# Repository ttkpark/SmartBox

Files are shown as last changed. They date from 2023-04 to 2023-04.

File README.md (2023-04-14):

# SmartBox

프로젝트 기간 : 2020.02.13~2020.04.30

## 프로젝트 소개 및 개발 이유

- 주로 음식물 창고를 대상으로, 음식물 저장 창고 각 상자에 스마트 제품을 부착함으로써 음식물의 보관시기 등을 상자와 관리 PC를 통해 알 수 있도록 하여 효율적으로 음식물을 관리하는 시스템이다. 스마트 박스가 사물인터넷 망으로 연결되어 보관 이후 얼마나 시간이 지났는지 인터넷 또는 로컬 서버로 데이터를 수집하고 관리한다.

### 역할 소개
- 서버+설계 +웹 담당 : 서비스 회원가입, 박스들의 등록, 데이터 수집 DB관리
- 기기 개발 담당 : 창고의 스마트 박스 장치 개발, 남은 기한에 따른 e-paper 표시
- **응용 프로그램 개발 담당 : 창고에서 박스의 등록, 초기화, 관리를 담당하는 MFC 응용 프로그램을 개발,**

- 본인이 맡은 부분은
- `/3D Model`, `/SmartBoxDaemon`, `/SmartBoxWinMonitoring`, `/WZMS_Sensors Code`이다.

## 개발 요소

- 본인은 관리PC에서 동작하는 응용프로그램 개발을 담당하였다. MFC 기반으로 스마트 박스와 연결해야 했기에 PC와 그 박스들을 무선으로 연결할 수 있는 AP(Access Point)장치를 만들었다. 이 장치를 마스터키라고 한다. 즉, 응용프로그램과 마스터키 무선 장치를 제작하였다.

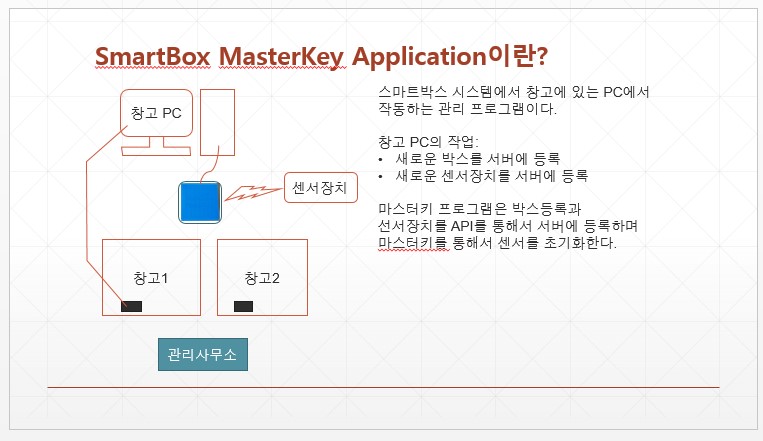
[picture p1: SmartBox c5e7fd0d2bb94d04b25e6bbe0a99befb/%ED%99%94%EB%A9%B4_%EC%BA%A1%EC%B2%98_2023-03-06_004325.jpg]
본인이 개발한 파트인 응용프로그램과 마스터키 무선 장치의 용도를 정의한 파워포인트 문서.


본인이 개발한 파트인 응용프로그램과 마스터키 무선 장치의 용도를 정의한 파워포인트 문서.

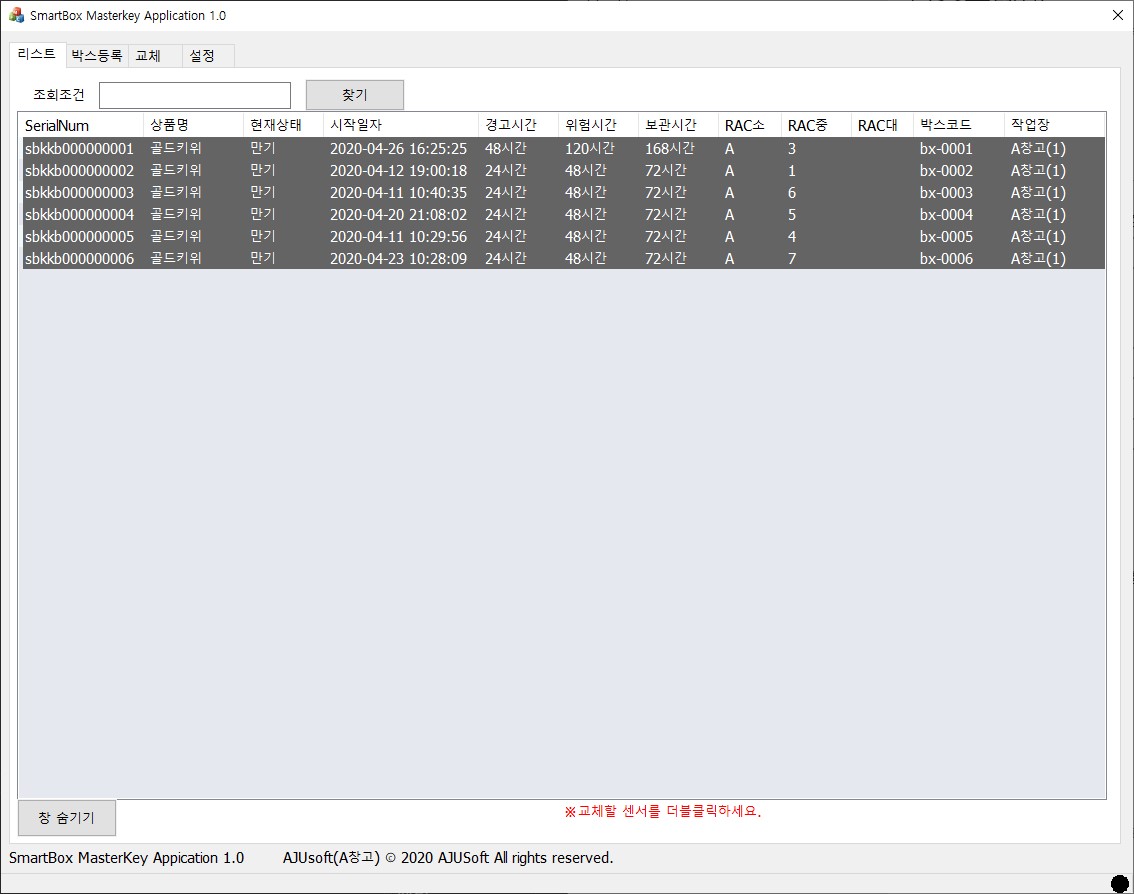
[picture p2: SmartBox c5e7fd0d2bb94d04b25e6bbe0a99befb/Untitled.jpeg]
응용프로그램의 동작화면. 모든 등록된 박스가 기한이 지난 상태이며 회색으로 표시돼 한눈에 확인할 수 있다.


응용프로그램의 동작화면. 모든 등록된 박스가 기한이 지난 상태이며 회색으로 표시돼 한눈에 확인할 수 있다.

- 스마트 박스 데이터를 업데이트 및 가져오기(서버와의 API 통신), 박스 등록하기(USB 시리얼로 마스터키와 통신), 언어설정(SQLite를 이용한 언어지원 관리), Tray Icon으로 숨기기 기능을 주로 구현했다.

## 어려움 및 극복사항

- MFC 교육을 받은 경험이 없어 모든 내용은 인터넷 검색과 대학교 교재를 찾아보아 구현하였다.
- 에러사항을 물어볼 곳이 없어 스스로 모든 문제를 인터넷을 통해 해결하였다.

## 협업 사항

- 응용프로그램 - 서버 간 API 통신으로 정보를 주고받았다. 이 때 서버 담당과의 의논을 통해 API 프로토콜을 결정했다.
- 박스 장치 - 응용프로그램 간 NRF 2.4Ghz RF 통신으로 정보를 주고받았다. 이 때의 프로토콜을 기기담당과 의논을 통해 결정했다.

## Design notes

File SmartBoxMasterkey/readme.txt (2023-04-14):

SmartBox Masterkey
마스터키 RF통신 , USB SerialComm 통신
기능
Lora 센서를 초기화, 컴퓨터 프로그램과 동기화하며 통신함.

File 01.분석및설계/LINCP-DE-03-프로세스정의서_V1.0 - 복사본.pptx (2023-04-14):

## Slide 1

목차
1. 사용자 정책 ........................................................................................................4
2. 업무처리 흐름도 ..........................................................................................6
(관리자 전체 흐름도).................................................................................5
PC-M-01 (로그인).............................................................................................7
PC-M-02 (로그아웃)...........................................................................................10
PC-M-03 (메인)...................................................................................12
PC-M-04 (회원정보변경).................................................................................15
PC-M-05 (헬프게시판)............................................................................18
PC-M-06 (관리자계정관리)....................................................................................22
PC-M-07 (DB관리)...................................................................................24
PC-M-08 (통계관리)......................................................................................33
PC-M-09 (게시판관리)…............................................................................38
PC-M-10 (예매데이터관제)…............................................................................48
PC-M-11 (회원관리).................................................................................................54
PC-M-12 (코드관리).................................................................................................63
PC-M-13 (시스템 연계 관리)...........................................................................................79
PC-M-14 (회원가입등록필드관리)..................................................................................................86

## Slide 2

0. 표기법

이벤트 시작/종료

데이터베이스

PC-01-01

프로세스

PC-01-01

수작업 프로세스

PC-01-06

문서

PC-01-06

수작업 문서

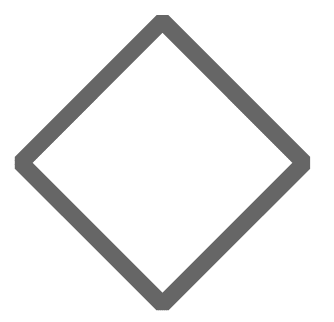
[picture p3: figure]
clip_image001

분기

데이터 흐름
(주요 엔터티 수준을 화살표 위에 표시)

※ 위 기호 외에 필요한 내용은 프로젝트 자체적으로 추가하여 사용할 수 있다.

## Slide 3

1. 사용자 정책

사용자 구분 | 사용자 분류 | 사용자 분류별 권한 | 예외사항 및 참고사항
관리자 | (일반)관리자 | *모든 기능 박스 등록 기능 센서 교체 기능 마스터키 포트 설정 기능 언어 설정 기능 선세 리스트 불러오기 기능 | 아이디/비밀번호 로그인 후 접근 가능

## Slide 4

관리자 전체 흐름도

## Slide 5

업무 처리 흐름도
단 계 | 설계 | 프로세스 ID | 없음 | 프로세스 명 | 관리자 전체 흐름도 | 작 성 자 | 박기호 | 승 인 자
설 명 | 공연예술통합관리시스템의 관리자 전체 업무 처리 흐름도

사용자구분 | 사용자분류 | 업무 절차
관리자 | 관리자, 슈퍼관리자

시작

로그인

센서 리스트

박스등록

센서교체

설정

다른 탭 클릭

종료버튼 클릭

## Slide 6

I. 로그인

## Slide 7

3. 업무처리 흐름도

PC-M-01

로그인

로그인

사용자구분 | 사용자분류 | 업무 절차
사용자 | 기획/제작사, 공연시설

N

시작

PC-M-01-01

로그인

PC-M-01-02

정보 일치 여부 확인

Y

인증 성공 여부

종료

N

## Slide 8

PC-M-01

로그인

로그인

엑티비티 | | | 수행자 | 산출물 | | 비고
ID | 명 | 설명 | | 입력 | 출력
PC-M-01-01 | 로그인 | 아이디/비밀번호를 통한 로그인 | 관리자 | 아이디/비밀번호
PC-M-01-02 | 정보 일치 여부 확인 | 아이디/비밀번호를 설정파일속에 설정된 서버로 전송 | 관리자 | 서버주소, 아이디/비밀번호 | 인증여부 | API(http)를 통해 송수신한다.

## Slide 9

II. 센서 리스트

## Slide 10

PC-M-02

메인

메인

사용자구분 | 사용자분류 | 업무 절차
관리자 | 관리자, 슈퍼관리자

PC-M-02-01

센서 리스트

시작

PC-M-02

센서 리스트

PC-M-02-02

검색

PC-M-02-03

창 숨기기(트레이)

PC-M-02-04

교체 센서 더블클릭

PC-M-04

교체 탭으로 이동

종료

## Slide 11

3. 업무처리 흐름도

PC-M-02

메인

메인

엑티비티 | | | 수행자 | 산출물 | | 비고
ID | 명 | 설명 | | 입력 | 출력
PC-M-02-01 | 센서 리스트 | 현재 작동 중인 센서들의 정보를 리스트로 표시 제일 윗부분을 클릭해 정렬을 할 수도 있음
PC-M-02-02 | 검색 | 텍스트박스에 있는 키워드를 리스트에 보이는 모든 내용에 검색하여 일치하는 행만 출력하도록 검색함
PC-M-02-03 | 창 숨기기(트레이) | 트레이 아이콘으로 창을 숨김
PC-M-02-04 | 교체 센서 더블클릭 | 더블클릭한 센서의 정보를 교체 탭으로 넘김. | | 더블클릭한 센서의 정보

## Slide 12

III. 박스 등록

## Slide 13

PC-M-03

메인

메인

사용자구분 | 사용자분류 | 업무 절차
관리자 | 관리자, 슈퍼관리자

시작

PC-M-03

박스등록

PC-M-03-02

센서/박스 준비 1

PC-M-03-03

센서/박스 준비 2

센서/박스 준비 1,2
*두가지 방법

PC-M-03-01

박스/센서 등록

종료

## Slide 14

3. 업무처리 흐름도

PC-M-03

메인

메인

엑티비티 | | | 수행자 | 산출물 | | 비고
ID | 명 | 설명 | | 입력 | 출력
PC-M-03-01 | 센서/박스 등록 | API를 통해서 서버에 박스/센서 정보 전송, 정상등록여부 확인 | | 입력한 정보, 박스 번호 | 성공여부
PC-M-03-02 | 선서/박스 준비1 | 센서를 먼저 켜는 경우(관리자 작업) | | | | 직접 수행
PC-M-03-03 | 선서/박스 준비2 | 박스번호를 먼저 찍는 경우(관리자 작업) | | | | 직접 수행

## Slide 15

PC-M-03-02

센서/박스 준비1

메인

사용자구분 | 사용자분류 | 업무 절차
관리자 | 관리자, 슈퍼관리자

시작

센서 전원ON

인식, 프로그램 메시지 띄움.

관리자 입력

※ 센서를
먼저 켜는
경우

전송버튼누름

센서 초기화, 박스 등록

종료

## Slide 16

PC-M-03-03

센서/박스 준비2

메인

사용자구분 | 사용자분류 | 업무 절차
관리자 | 관리자, 슈퍼관리자

시작

박스번호 입력

센서 인식 대기
사용자 입력 대기

※ 바코드를 먼저 찍는
경우

입력완성 및
전송버튼 누름

센서 초기화, 박스 등록

종료

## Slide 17

PC-M-03-01

센서/박스 등록

메인

사용자구분 | 사용자분류 | 업무 절차
관리자 | 관리자, 슈퍼관리자

시작

내용 확인

내용ok?

Y

센서 초기화

BOX등록
API전송

N

에러 메시지 표시.

종료

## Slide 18

IV. 센서 교체

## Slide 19

PC-M-04

메인

메인

사용자구분 | 사용자분류 | 업무 절차
관리자 | 관리자, 슈퍼관리자

시작

PC-M-04

메인

교체할 센서 더블클릭

새로운 센서 ON

교체 버튼 클릭

PC-M-04-01

종료

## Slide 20

3. 업무처리 흐름도

PC-M-04

메인

메인

엑티비티 | | | 수행자 | 산출물 | | 비고
ID | 명 | 설명 | | 입력 | 출력
PC-M-04-01 | 교체 버튼 클릭 | | | 센서 정보 | 성공여부

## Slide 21

V. 설정

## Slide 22

PC-M-05

메인

메인

사용자구분 | 사용자분류 | 업무 절차
관리자 | 관리자, 슈퍼관리자

PC-M-05-01

전송처별 예매DB수신현황

시작

PC-M-05

메인

PC-M-05-02

DB등록현황

PC-M-05-03

미매핑예매정보현황

PC-M-05-04

정보수정요청내역

종료

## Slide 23

3. 업무처리 흐름도

PC-M-05

메인

메인

엑티비티 | | | 수행자 | 산출물 | | 비고
ID | 명 | 설명 | | 입력 | 출력
PC-M-05-01 | 전송처별 예매 DB 수신현황 | 전일 기준 연계 시설 별 에매매수, 취소매수, 최종 매수 를 그래프 및 숫자로 표시
PC-M-05-02 | DB 등록현황 | 연계기관 및 OPENAPI를 통한 공연정보 등록 현황 을 표시 기획/제작사 등록 숫자 표시 공연시설 등록 숫자 표시
PC-M-05-03 | 미매핑정보현황 | 미매핑 숫자 표시
PC-M-05-04 | 정보수정요청내역 | 정보수정요청 건수 표시

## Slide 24

III. 메인

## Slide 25

PC-M-03

메인

메인

사용자구분 | 사용자분류 | 업무 절차
관리자 | 관리자, 슈퍼관리자

PC-M-03-01

마스터키 통신포트 설정

시작

PC-M-03

메인

PC-M-03-02

언어 설정

PC-M-03-03

센서 정보 불러오기

종료

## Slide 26

3. 업무처리 흐름도

PC-M-03

메인

메인

엑티비티 | | | 수행자 | 산출물 | | 비고
ID | 명 | 설명 | | 입력 | 출력
PC-M-03-01 | 마스터키 통신포트 설정 | 마스터키 연결 에 필요한 COM포트 설정 자동검색 기능 이용
PC-M-03-02 | 언어 설정 | 언어 설정
PC-M-03-03 | 센서 정보 불러오기 | 센서 리스트 다시 불러오기

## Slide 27

IX. 게시판 관리

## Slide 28

PC-M-09

게시판관리

게시판 관리

사용자구분 | 사용자분류 | 업무 절차
관리자 | 관리자/ 슈퍼관리자

시작

PC-M-09-01

공지사항 관리

PC-M-09

게시판 관리

PC-M-09-02

팝업존 관리

PC-M-09-03

FAQ 관리

PC-M-09-04

정보 수정 요청 관리

PC-M-09-05

OPEN API 신청 관리

PC-M-09-07

OPEN API FAQ 관리

PC-M-09-06

입력필드설명문구 관리

종료

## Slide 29

PC-M-09-01

공지사항 관리

공지사항 관리

사용자구분 | 사용자분류 | 업무 절차
관리자 | 관리자/ 슈퍼관리자

시작

PC-M-09-01-04

공지사항 삭제

PC-M-09-01-01

공지사항 목록

PC-M-09-01-05

공지사항 등록

PC-M-09-01-02-

공지사항 상세보기

PC-M-09-01-03

공지사항 수정

종료

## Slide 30

PC-M-09-01

공지사항 관리

공지사항 관리

엑티비티 | | | 수행자 | 산출물 | | 비고
ID | 명 | 설명 | | 입력 | 출력
PC-M-09-01-01 | 공지사항 목록 | 공지사항 목록 | 관리자/슈퍼관리자
PC-M-09-01-02 | 공지사항 상세 보기 | 공지사항 상세 보기 | 관리자/슈퍼관리자
PC-M-09-01-03 | 공지사항 수정 | 공지사항 수정 | 관리자/슈퍼관리자
PC-M-09-01-04 | 공지사항 삭제 | 공지사항 삭제 | 관리자/슈퍼관리자
PC-M-09-01-05 | 공지사항 등록 | 공지사항 등록 | 관리자/슈퍼관리자

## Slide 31

PC-M-09-02

팝업존 관리

팝업존 관리

사용자구분 | 사용자분류 | 업무 절차
관리자 | 관리자/ 슈퍼관리자

시작

PC-M-09-02-01

팝업존 목록

PC-M-09-02-04

팝업존 정보 삭제

PC-M-09-02-05

팝업존 등록

PC-M-09-02-02-

팝업존 상세 보기

종료

PC-M-09-02-03

팝업존 정보 수정

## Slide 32

PC-M-09-02

팝업존 관리

팝업 존 관리

엑티비티 | | | 수행자 | 산출물 | | 비고
ID | 명 | 설명 | | 입력 | 출력
PC-M-09-02-01 | 팝업존 목록 | 팝업존 목록 | 관리자/슈퍼관리자 | 팝업창명 | 팝업창명, 게시기간, 게시상태
PC-M-09-02-02 | 팝업존 상세 보기 | 팝업존 상세 보기 | 관리자/슈퍼관리자 | | 팝업창명, 게시기간, 그만보기 설정유무, 게시상태, 팝업내용
PC-M-09-02-03 | 팝업존 수정 | 팝업존 수정 | 관리자/슈퍼관리자 | | 팝업창명, 게시기간, 그만보기 설정유무, 게시상태, 팝업내용
PC-M-09-02-04 | 팝업존 삭제 | 팝업존 삭제 | 관리자/슈퍼관리자
PC-M-09-02-05 | 팝업존 등록 | 팝업존 등록 | 관리자/슈퍼관리자 | | 팝업창명, 게시기간, 그만보기 설정유무, 게시상태, 팝업내용

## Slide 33

PC-M-09-03

FAQ 관리

FAQ 관리

사용자구분 | 사용자분류 | 업무 절차
관리자 | 관리자/ 슈퍼관리자

시작

FAQ 질문
상세 보기

PC-M-09-03-02-

PC-M-09-03-03

FAQ 수정

PC-M-09-03-01

FAQ 목록

PC-M-09-03-04

FAQ 삭제

PC-M-09-03-05

FAQ 등록

종료

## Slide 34

PC-M-09-03

FAQ 관리

FAQ 관리

엑티비티 | | | 수행자 | 산출물 | | 비고
ID | 명 | 설명 | | 입력 | 출력
PC-M-09-03-01 | FAQ 목록 | FAQ 목록 | 관리자/슈퍼관리자 | 질문 제목 | 질문제목, 질문분류, 조회수, 등록일자
PC-M-09-03-02 | FAQ 상세 보기 | FAQ 상세 보기 | 관리자/슈퍼관리자 | | 질문제목, 질문분류, 답변내용, 조회수, 등록일자
PC-M-09-03-03 | FAQ 수정 | FAQ 수정 | 관리자/슈퍼관리자 | 질문제목, 질문분류, 답변내용
PC-M-09-03-04 | FAQ 삭제 | FAQ 삭제 | 관리자/슈퍼관리자
PC-M-09-04-05 | FAQ 등록 | FAQ 등록 | 관리자/슈퍼관리자 | 질문제목, 질문분류, 답변내용

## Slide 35

PC-M-09-04

정보수정요청관리

정보 수정 요청 관리

사용자구분 | 사용자분류 | 업무 절차
관리자 | 관리자/ 슈퍼관리자

시작

정보 수정 요청
상세 보기

PC-M-09-04-02-

PC-M-09-04-01

PC-M-09-04-03

정보 수정 요청
목록

정보 수정 요청
삭제

PC-M-09-04-04

정보 수정 요청 답변

종료

PC-M-09-04-05

정보 수정 요청 접수 처리

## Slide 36

PC-M-09-04

정보 수정 요청 관리

정보 수정 요청 관리

엑티비티 | | | 수행자 | 산출물 | | 비고
ID | 명 | 설명 | | 입력 | 출력
PC-M-09-04-01 | 정보 수정 요청 목록 | 정보 수정 요청 목록 | 관리자/슈퍼관리자 | 요청대상, 작성자 | 구분, 요청대상, 요청자, 진행상태, 최종수정일
PC-M-09-04-02 | 정보 수정 요청 상세 보기 | 정보 수정 요청 상세 보기 | 관리자/슈퍼관리자 | | 요청대상, 요청내용, 첨부파일, 요청자, 요청자 연락처, 요청자 이메일주소, 진행상태, 정보출처
PC-M-09-04-03 | 정보 수정 요청 삭제 | 정보 수정 요청 삭제 | 관리자/슈퍼관리자
PC-M-09-04-04 | 정보 수정 요청 답변 | 정보 수정 요청 답변 | 관리자/슈퍼관리자 | 진행상태 | | 답변은 이메일/SMS로 발송됨.
PC-M-09-04-05 | 정보 수정 요청 접수 처리 | 정보 수정 요청 접수 처리 | 관리자/슈퍼관리자

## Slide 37

PC-M-09-05

OPEN API 신청 관리

OPEN API 신청 관리

사용자구분 | 사용자분류 | 업무 절차
관리자 | 관리자/ 슈퍼관리자

시작

PC-M-09-05-02-

OPEN API 신청
상세 보기

PC-M-09-05-01

OPEN API 신청
목록

종료

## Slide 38

PC-M-09-05

OPEN API 신청 관리

OPEN API 신청 관리

엑티비티 | | | 수행자 | 산출물 | | 비고
ID | 명 | 설명 | | 입력 | 출력
PC-M-09-05-01 | OPEN API 신청 목록 | OPEN API 신청 목록 | 관리자/슈퍼관리자 | 신청자, 기관 | 신청자, 기관, 신청 분류
PC-M-09-05-02 | OPEN API 신청 상세 보기 | OPEN API 신청 상세 보기 | 관리자/슈퍼관리자 | | 신청자, 연락처, 이메일, 기관, 신청분류, 발급 KEY, 신청 일자

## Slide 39

PC-M-09-07

OPEN API FAQ 관리

OPEN API FAQ 관리

사용자구분 | 사용자분류 | 업무 절차
관리자 | 관리자/ 슈퍼관리자

시작

OPEN API FAQ 질문
상세 보기

PC-M-09-07-02-

PC-M-09-07-03

OPEN API FAQ 수정

PC-M-09-07-01

OPEN API FAQ 목록

PC-M-09-07-04

OPEN API FAQ 삭제

PC-M-09-07-05

OPEN API FAQ 등록

종료

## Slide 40

PC-M-09-07

OPEN API FAQ 관리

OPEN API FAQ 관리

엑티비티 | | | 수행자 | 산출물 | | 비고
ID | 명 | 설명 | | 입력 | 출력
PC-M-09-07-01 | OPEN API FAQ 목록 | OPEN API FAQ 목록 | 관리자/슈퍼관리자 | 질문 제목 | 질문제목, 질문분류, 조회수, 등록일자
PC-M-09-07-02 | OPEN API FAQ 상세 보기 | OPEN API FAQ 상세 보기 | 관리자/슈퍼관리자 | | 질문제목, 질문분류, 답변내용, 조회수, 등록일자
PC-M-09-07-03 | OPEN API FAQ 수정 | OPEN API FAQ 수정 | 관리자/슈퍼관리자 | 질문제목, 질문분류, 답변내용
PC-M-09-07-04 | OPEN API FAQ 삭제 | OPEN API FAQ 삭제 | 관리자/슈퍼관리자
PC-M-09-07-05 | OPEN API FAQ 등록 | OPEN API FAQ 등록 | 관리자/슈퍼관리자 | 질문제목, 질문분류, 답변내용

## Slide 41

PC-M-09-06

입력필드설명문구 관리

입력필드설명문구 관리

사용자구분 | 사용자분류 | 업무 절차
관리자 | 관리자/ 슈퍼관리자

시작

입력필드설명문구
상세 보기

PC-M-09-06-03-

PC-M-09-06-05

입력필드설명문구 수정

PC-M-09-06-01

입력필드설명문구 목록

PC-M-09-06-06

입력필드설명문구 삭제

PC-M-09-06-04

입력필드설명문구 등록

종료

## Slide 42

PC-M-09-06

입력필드설명문구 관리

입력필드설명문구 관리

엑티비티 | | | 수행자 | 산출물 | | 비고
ID | 명 | 설명 | | 입력 | 출력
PC-M-09-06-01 | 입력필드설명문구 목록 | 입력필드설명문구 목록 | 관리자/슈퍼관리자 | | 제목, 조회수, 등록일자
PC-M-09-06-02 | 입력필드설명문구 검색 | 입력필드설명문구 검색 기능 | 관리자/슈퍼관리자 | | 제목, 조회수, 등록일자
PC-M-09-06-03 | 입력필드설명문구 등록 | 입력필드설명문구 등록 | 관리자/슈퍼관리자 | 제목, 내용
PC-M-09-06-04 | 입력필드설명문구 상세 | 입력필드설명문구 상세 | 관리자/슈퍼관리자 | | 제목, 내용, 등록일자
PC-M-09-06-05 | 입력필드설명문구 수정 | 입력필드설명문구 수정 | 관리자/슈퍼관리자 | 제목, 내용 | 제목, 내용, 등록일자
PC-M-09-06-05 | 입력필드설명문구 삭제 | 입력필드설명문구 삭제 | 관리자/슈퍼관리자

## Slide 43

X. 예매 데이터 관제

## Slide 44

PC-M-10

예매 데이터 관제

예매 데이터 관제

사용자구분 | 사용자분류 | 업무 절차
관리자 | 관리자/ 슈퍼관리자

시작

PC-M-10-01

미매핑 예매 정보 현황

PC-M-10-02

전체 예매 정보 현황

PC-M-10-03

미매핑 공연 현황

PC-M-10-04

판매대행사 매핑 관리

종료

PC-M-10-05

판매대행사 중복 관리

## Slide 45

PC-M-10-01

미매핑 예매 정보 현황

미매핑 예매 정보 현황

사용자구분 | 사용자분류 | 업무 절차
관리자 | 관리자/ 슈퍼관리자

시작

PC-M-10-02-03

미매핑 공연 정보 등록

PC-M-10-01-01

PC-M-10-01-02

미매핑 공연 정보 삭제

미매핑 예매 정보
목록

PC-M-10-01-04

미매핑 공연 정보 엑셀 저장

종료

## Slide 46

PC-M-10-01

미매핑 정보 현황

미매핑 정보 현황

엑티비티 | | | 수행자 | 산출물 | | 비고
ID | 명 | 설명 | | 입력 | 출력
PC-M-10-01-01 | 미매핑 예매 정보 목록 | 미매핑 예매 정보 목록 | 관리자/슈퍼관리자 | 시설명 | 시설공연코드, 시설명, 공연명,공연일시, 전송일시
PC-M-10-01-02 | 미매핑 공연 정보 삭제 | 미매핑 공연 정보 삭제 | 관리자/슈퍼관리자
PC-M-10-01-03 | 미매핑 공연 정보 등록 하기 | 미매핑 공연 정보 등록 하기 | 관리자/슈퍼관리자 | 공연정보 등록으로 자동 연결 되며, 시설공연코드, 공연명, 공연일시 등을 자동으로 가져감.
PC-M-10-01-04 | 미매핑 공연 정보 엑셀 저장 | 미매핑 공연 정보 엑셀 저장 | 관리자/슈퍼관리자

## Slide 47

PC-M-10-02

전체예매정보현황

전체 예매 정보 현황

사용자구분 | 사용자분류 | 업무 절차
관리자 | 관리자/ 슈퍼관리자

시작

전체 예매 정보
목록

PC-M-10-02-01

PC-M-10-02-02

전체 예매 정보
엑셀 저장

공연정보유입현황
목록

PC-M-10-02-03

PC-M-10-02-04

공연정보유입현황
상세보기

공연정보유입현황
엑셀 저장

PC-M-10-02-05

종료

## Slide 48

PC-M-10-02

전체 예매 현황

전체 예매 현황

엑티비티 | | | 수행자 | 산출물 | | 비고
ID | 명 | 설명 | | 입력 | 출력
PC-M-10-02-01 | 예매 정보 현황 목록 | 예매 정보 현황 목록 | 관리자/슈퍼관리자 | 시설명, 수집일시 | 수집일시, 시설명, 예매관객수, 취소관객수, 총관객수, 예매매출액, 취소매출액, 총매출액
PC-M-10-02-02 | 예매 정보 현황 엑셀 저장 | 예매 정보 현황 엑셀 저장 | 관리자/슈퍼관리자
PC-M-10-02-03 | 공연 정보 유입 현황 | 공연 정보 유입 현황 | 관리자/슈퍼관리자 | 등록구분, 유입일자 | 등록구분, 유입일자, 유입건수
PC-M-10-02-04 | 공연 정보 유입 현황 상세보기 | 공연 정보 유입 현황 상세보기 | 관리자/슈퍼관리자
PC-M-10-02-05 | 공연 정보 유입 현황 엑셀 저장 | 공연 정보 유입 현황 엑셀 저장 | 관리자/슈퍼관리자

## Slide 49

PC-M-10-03

미매핑공연현황

신규 수신된 연계 공연에 대한 미매핑 처리 (신규 등록 OR 자동 매핑 처리 결정)

사용자구분 | 사용자분류 | 업무 절차
관리자 | 관리자/ 슈퍼관리자

시작

PC-M-10-03-01

미매핑공연 목록

PC-M-10-03-02

미매핑공연 검색

관리자 공연/공연시설/공연장 신규 등록

기존에 등록된 공연과
중복되는가 확인

중복이 아닌 경우

중복인 경우

PC-M-10-03-03

종료

공연/공연시설/공연장 자동 매핑 등록

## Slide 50

PC-M-10-03

미매핑공연현황

신규 수신된 연계 공연에 대한 미매핑 처리 (신규 등록 OR 매핑 처리 결정)

엑티비티 | | | 수행자 | 산출물 | | 비고
ID | 명 | 설명 | | 입력 | 출력
PC-M-10-03-01 | 미매핑 공연 현황 목록 | 미매핑 공연 현황 목록 | 관리자/슈퍼관리자 | 판매대행사, 공연명, 수집일시 | 판매대행사, 공연명, 공연시설명, 공연장명,공연기간, 공연시설코드, 공연장코드, 시설공연코드
PC-M-10-03-02 | 미매핑 공연 검색 | 미매핑 공연이 기존 공연으로 등록 되어있는지 검색하는 팝업화면 | 관리자/슈퍼관리자 | 공연명, 공연기간 | 판매대행사, 공연명, 공연시설명, 공연장명,공연기간, 공연시설코드, 공연장코드, 시설공연코드
PC-M-10-03-03 | 공연/공연시설/공연장 자동매핑등록 | 동일한 공연이고 판매대행사만 다르므로 공연/공연시설, 공연장 자동 매핑 처리 | 관리자/슈퍼관리자 | 매핑 대상 공연, 매핑 타켓 공연

미매핑 공연 현황

판매대행사 매핑 관리

판매대행사 중복 관리

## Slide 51

PC-M-10-04

판매대행사 매핑관리

판매대행사별로 사실상 동일한 공연 매핑 관리

사용자구분 | 사용자분류 | 업무 절차
관리자 | 관리자/ 슈퍼관리자

PC-M-10-04-01

공연매핑 목록/검색

PC-M-10-04-02

공연 매핑 상세

PC-M-10-04-04

공연 매핑 삭제

PC-M-10-04-09

공연시설 매핑 삭제

PC-M-10-04-15

공연장 매핑 수정

PC-M-10-04-05

공연 매핑 수정

시작

종료

PC-M-10-04-03

공연 매핑 등록

PC-M-10-04-10

공연시설 매핑 수정

PC-M-10-04-06

공연시설매핑 목록/검색

PC-M-10-04-07

공연시설 매핑 상세

PC-M-10-04-08

공연시설 매핑 등록

PC-M-10-04-11

공연장 매핑 목록/검색

PC-M-10-04-12

공연장 매핑 상세

PC-M-10-04-13

공연장 매핑 등록

PC-M-10-04-14

공연장 매핑 삭제

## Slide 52

PC-M-10-04

판매대행사 매핑관리

판매대행사 별로 사실상 동일한 공연, 공연시설, 공연장에 대한 매핑 관리

엑티비티 | | | 수행자 | 산출물 | | 비고
ID | 명 | 설명 | | 입력 | 출력
PC-M-10-04-01 | 공연 매핑 목록/검색 | 공연 매핑 목록/검색 | 관리자/슈퍼관리자 | 공연명, 공연시설, 공연장, 공연기간 | 판매대행사, 매핑 공연명, 공연기간, 공연시설, 공연장 매핑된 판매대행사
PC-M-10-04-02 | 공연 매핑 상세 | 공연 매핑 상세 | 관리자/슈퍼관리자 | | 판매대행사, 매핑 공연명, 공연기간, 공연시설, 공연장, 시설공연코드 매핑된 판매대행사, 매핑된 판매대행사 공연시설코드, 매핑된 판매대행사 공연장코드, 매핑된 판매대행사 공연코드
PC-M-10-03-03 | 공연 매핑 등록 | 공연 매핑 등록 | 관리자/슈퍼관리자 | 판매대행사, 매핑 공연명, 공연기간, 공연시설, 공연장, 시설공연코드 매핑할 판매대행사, 매핑할 판매대행사 시설공연 코드
PC-M-10-03-04 | 공연 매핑 삭제 | 공연 매핑 삭제 | 관리자/슈퍼관리자 | 삭제할 판매대행사코드, 매핑 공연 코드
PC-M-10-03-05 | 공연 매핑 수정 | 공연 매핑 수정 | 관리자/슈퍼관리자 | 판매대행사, 매핑 공연명, 공연기간, 공연시설, 공연장, 시설공연코드 매핑할 판매대행사, 매핑할 판매대행사 시설공연 코드

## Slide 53

PC-M-10-04

판매대행사 매핑관리

판매대행사 별로 사실상 동일한 공연, 공연시설, 공연장에 대한 매핑 관리

엑티비티 | | | 수행자 | 산출물 | | 비고
ID | 명 | 설명 | | 입력 | 출력
PC-M-10-04-06 | 공연시설 매핑 목록/검색 | 공연시설 매핑 목록/검색 | 관리자/슈퍼관리자 | 공연시설, 공연장, 공연기간 | 판매대행사, 매핑 공연시설, 매핑된 판매대행사,
PC-M-10-04-07 | 공연시설 매핑 상세 | 공연시설 매핑 상세 | 관리자/슈퍼관리자 | | 판매대행사, 공연시설명, 공연시설코드 매핑된 판매대행사, 매핑된 판매대행사 공연시설코드,
PC-M-10-03-08 | 공연시설 매핑 등록 | 공연시설 매핑 등록 | 관리자/슈퍼관리자 | 판매대행사, 공연시설명, 공연시설코드 매핑된 판매대행사, 매핑된 판매대행사 공연시설코드,
PC-M-10-03-09 | 공연시설 매핑 삭제 | 공연시설 매핑 삭제 | 관리자/슈퍼관리자 | 삭제할 판매대행사코드, 매핑 공연시설 코드
PC-M-10-03-10 | 공연시설 매핑 수정 | 공연시설 매핑 수정 | 관리자/슈퍼관리자 | 판매대행사, 공연시설명, 공연시설코드 매핑할 판매대행사, 매핑할 판매대행사 공연시설코드,

미매핑 공연 현황

판매대행사 매핑 관리

판매대행사 중복 관리

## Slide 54

PC-M-10-04

판매대행사 매핑관리

판매대행사 별로 사실상 동일한 공연, 공연시설, 공연장에 대한 매핑 관리

엑티비티 | | | 수행자 | 산출물 | | 비고
ID | 명 | 설명 | | 입력 | 출력
PC-M-10-04-11 | 공연장 매핑 목록/검색 | 공연장 매핑 목록/검색 | 관리자/슈퍼관리자 | 공연시설, 공연장, 공연기간 | 판매대행사, 매핑 공연장, 매핑된 판매대행사,
PC-M-10-04-12 | 공연장 매핑 상세 | 공연장 매핑 상세 | 관리자/슈퍼관리자 | | 판매대행사, 공연시설명, 공연시설코드, 공연장명, 공연장 코드 매핑된 판매대행사, 매핑된 판매대행사 공연시설코드,, 매핑된 공연장코드
PC-M-10-03-13 | 공연장 매핑 등록 | 공연장 매핑 등록 | 관리자/슈퍼관리자 | 판매대행사, 공연시설명, 공연시설코드, 공연장코드 매핑된 판매대행사, 매핑된 판매대행사 매핑된 공연시설코드, 매핑된 공연장코드
PC-M-10-03-14 | 공연장 매핑 삭제 | 공연장 매핑 삭제 | 관리자/슈퍼관리자 | 삭제할 판매대행사코드, 매핑 공연시설 코드, 매핑된 공연장 코드
PC-M-10-03-15 | 공연장 매핑 수정 | 공연장 매핑 수정 | 관리자/슈퍼관리자 | 판매대행사, 공연시설명, 공연시설코드, 공연장코드 매핑할 판매대행사, 매핑할 판매대행사 공연시설코드, 공연장코드

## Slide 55

PC-M-10-05

판매대행사 중복관리

판매대행사별로 통계에 중복 등록된 판매대행사별 공연, 공연장, 공연시설 을 통합처리

사용자구분 | 사용자분류 | 업무 절차
관리자 | 관리자/ 슈퍼관리자

PC-M-10-05-01

통합대상 공연 목록/조회

시작

PC-M-10-05-02

통합목표 공연 목록/조회

PC-M-10-05-03

공연 통합

PC-M-10-05-04

통합대상 공연시설 목록/조회

시작

PC-M-10-05-06

공연 시설 통합

PC-M-10-05-05

통합 목표 공연시설 목록/조회

시작

PC-M-10-05-07

통합대상 공연 목록/조회

PC-M-10-05-09

공연장 통합

종료

PC-M-10-05-08

통합목표 공연 목록/조회

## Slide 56

PC-M-10-05

판매대행사 중복관리

판매대행사별로 통계에 중복 등록된 판매대행사별 공연, 공연장, 공연시설 을 통합처리

엑티비티 | | | 수행자 | 산출물 | | 비고
ID | 명 | 설명 | | 입력 | 출력
PC-M-10-05-01 | 통합대상 공연 목록/조회 | 통합대상 공연 목록/조회 | 관리자/슈퍼관리자 | 판매대행사, 공연시설, 공연장, 공연기간 | 판매대행사, 공연시설, 공연장, 공연명, 공연기간
PC-M-10-05-02 | 통합목표 공연 목록/조회 | 통합목표 공연 목록/조회 | 관리자/슈퍼관리자 | 판매대행사, 공연시설, 공연장, 공연기간 | 판매대행사, 공연시설, 공연장, 공연명, 공연기간
PC-M-10-05-03 | 공연 통합 | 공연 통합 | 관리자/슈퍼관리자 | 통합대상 판매대행사 및 공연코드 통합목표 판매대행사및 공연코드
PC-M-10-05-04 | 통합대상 공연시설 목록/조회 | 통합대상 공연시설 목록/조회 | 관리자/슈퍼관리자 | 판매대행사, 공연시설 | 판매대행사, 공연시설
PC-M-10-05-05 | 통합목표 공연시설 목록/조회 | 통합목표 공연시설 목록/조회 | 관리자/슈퍼관리자 | 판매대행사, 공연시설 | 판매대행사, 공연시설
PC-M-10-05-06 | 공연시설 통합 | 공연시설 통합 | 관리자/슈퍼관리자 | 통합대상 판매대행사 및 공연시설코드 통합목표 판매대행사및 공연시설코드
PC-M-10-05-07 | 통합대상 공연장 목록/조회 | 통합대상 공연장 목록/조회 | 관리자/슈퍼관리자 | 판매대행사, 공연시설, 공연장 | 판매대행사, 공연시설, 공연장
PC-M-10-05-08 | 통합목표 공연장 목록/조회 | 통합목표 공연장 목록/조회 | 관리자/슈퍼관리자 | 판매대행사, 공연시설, 공연장 | 판매대행사, 공연시설, 공연장
PC-M-10-05-09 | 공연장 통합 | 공연장 통합 | 관리자/슈퍼관리자 | 통합대상 판매대행사 및 공연장코드 통합목표 판매대행사및 공연장코드

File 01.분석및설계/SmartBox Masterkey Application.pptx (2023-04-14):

## SmartBox Masterkey Application

2020.03.04~2020.03.05 박기호

## 목차

- SmartBox Masterkey Application 설명
- Masterkey Application 윈도우 폼 설명
- Masterkey Application 사용법

## 1. SmartBox Masterkey Application 설명

## SmartBox MasterKey Application이란?

창고 PC

스마트박스 시스템에서 창고에 있는 PC에서 작동하는 관리 프로그램이다.
창고 PC의 작업:
- 새로운 박스를 서버에 등록
- 새로운 센서장치를 서버에 등록
마스터키 프로그램은 박스등록과 선서장치를 API를 통해서 서버에 등록하며
마스터키를 통해서 센서를 초기화한다.

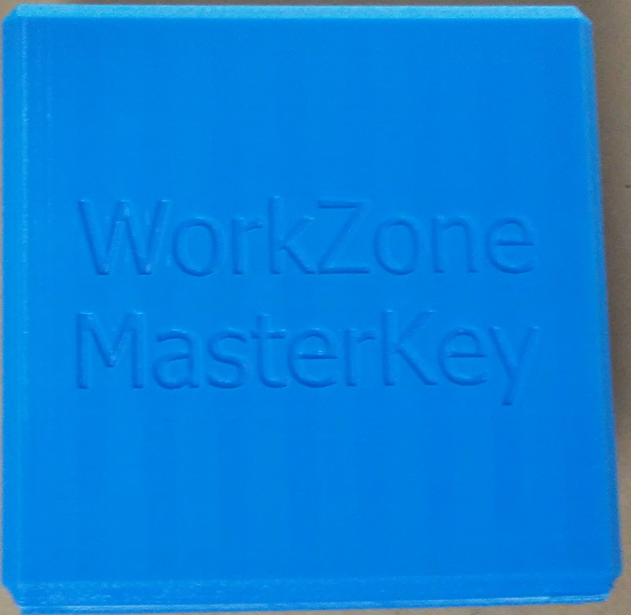
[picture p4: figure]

센서장치

창고1

창고2

관리사무소

## MasterKey Application의 동작 – 센서의 접근

- 센서가 동작하기 위해서는 기본값이 저장되어 있어야 한다.
- 센서접근 : 초기화를 위해 센서를 PC에 인식시키는 작업이다.
- 초기화되어 아무 데이터도 없는 상태에서 센서 전원을 켜면
RF통신(nRF24)을 통해 마스터키에게 신호를 주고받는데,
이것을 접근했다고 한다.
- 접근 직후에 마스터키는 Masterkey Application에 접근장치의 번호를 보내고 App에서 번호를 받아 처리한다.
- 이후 App이 보낼 준비되면 데이터를 보내 센서를 초기화한다.

## 초기화 작업 흐름

관리자 서버
또는
컴퓨터

API,인터넷

MasterKey Application

초기화 설정 값

MasterKey

초기화 설정 값

장치
(상자)

순서 | 서버 | <-> | Masterkey Application | <-> | MasterKey | <-> | 장치
1 | 기본정보* | -> | 프로그램 내부 저장
2 | | | 번호 저장 | <- | 전달 | <- | 고유번호
3 | | | 고유번호의 기본정보* | -> | 전달 | -> | 초기화(후 연결 끊음)

## SmartBox MasterKey와의 통신

1. 상태확인 (인터럽트X)
PC -> Masterkey : STX+s+ETX
1. PC <- Masterkey : STX+A+ETX : 접근대기
2. PC <- Masterkey : STX+B+ETX : App 수신대기
3. PC <- Masterkey : 센서가 접근했다!
STX+NDT+ENQ+sbkkb000000001+US(1F)+01+ETX
2. 데이터 전송 (컴퓨터 -> 마스터키)
송신 : PC -> Masterkey : STX+NDT+ENQ+(Hex)LENGTH(4Byte)
+ hexCode(LEN*2 Byte)+US(1F)+01+ETX
취소 : PC -> Masterkey : STX+NDT+ENQ+00+US(1F)+00+ETX
PC <- Masterkey : STX+RTN+ENQ+NDT+US(1F)+01(00)+ETX

※ 센서 기본값(기본정보) 상세 내용

*기본정보 | 예)
상품명 | 골드키위
시작시간 | 2020-02-19 10:43:38
경고기간(분) | 5760
위험기간(분) | 7201
보관기간(분) | 10080
전송주기(초) | 43200
보정값 | TP^-5,HU^10
RAC정보 | A(LL,대) 1(MM,중) 2(SS,소)
APPKEY | sbkk00010003
교체 flag | 1 or 0
범위 정보 | Range(“TP“,범위 4개)

## SmartBox MasterKey와의 통신

1. 작동확인(자동검색 시 사용됨.)
PC -> Masterkey : STX+e+ETX
PC <- Masterkey : STX+ACK(06)+ETX
2. 센서 접근 (컴퓨터 <- 마스터키)
PC <- Masterkey : STX+NDT+ENQ+sbkkb000000001+US(1F)+01+ETX
3. 데이터 전송 (컴퓨터 -> 마스터키)
PC -> Masterkey : STX+NDT+ENQ+(Hex)LENGTH(4Byte)
+ hexCode(LEN*2 Byte)+US(1F)+01+ETX
PC <- Masterkey : STX+RTN+ENQ+NDT+US(1F)+01(00)+ETX

※ 센서 기본값(기본정보) 상세 내용

*기본정보 | 예)
상품명 | 골드키위
시작시간 | 2020-02-19 10:43:38
경고기간(분) | 5760
위험기간(분) | 7201
보관기간(분) | 10080
전송주기(초) | 43200
보정값 | TP^-5,HU^10
RAC정보 | A(LL,대) 1(MM,중) 2(SS,소)
APPKEY | sbkk00010003

## 2. Masterkey Application 윈도우 폼 설명

## SB Masterkey App 폼

- 다이얼로그 기반이다.(확대 축소 불가.)
- 탭은 총 4개로 구성되어 있다.
  1. 리스트 탭 : 현재 작동 중인 센서의 리스트.
  2. 박스 등록 : 박스와 센서 장치를 초기화한다.
  3. 교체 탭 : 센서 교체 관련 작업을 수행한다.
  4. 설정 탭 : 마스터키 연결, 언어 등에 관해 설정한다.
- 상태 표시줄은 상태 메시지와 상태 아이콘으로 이루어져 있다.
  - 상태 매시지 : 현재 상태를 출력한다.
  - 상태 아이콘 : 현재 상태를 아이콘으로 출력한다.

: 마스터키와 연결 되어 있습니다.

SmartBox Masterkey App 1.0

리스트

박스 등록

교체

설정

탭

X

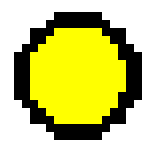
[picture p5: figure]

상태 표시줄

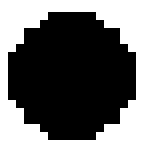
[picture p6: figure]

: 마스터키와 연결이 안 돼 있습니다.

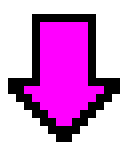
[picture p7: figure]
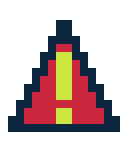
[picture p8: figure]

: 센서초기화를 위한 사용자의 입력을 기다리고 있습니다.

: 마스터키 통신 인식 중 오류가 발생했습니다.

## 탭1. 리스트 탭

센서번호 | 상품명 | 시작날짜 | 위험시간 | ...
sbkkb000000002 | 골드키위 | 2020.02.02 | 64시간 | …
sbkkb000000003 | 골드키위 | 2020.02.03 | 64시간 | …
sbkkb000000005 | 골드키위 | 2020.02.02 | 64시간 | …
sbkkb000000007 | 골드키위 | 2020.02.03 | 64시간 | …

※ 센서 교체시 더블클릭하세요.

- 현재 작동중인 센서의 정보를 표시함.
- 센서의 고장 등의 이유로 센서를 교체하고자 할 때는
- 교체하고자 하는 센서를 더블클릭한다.
(-> 3.교체 탭으로 넘어감.)

## 탭2. 박스 등록(센서장치 등록)

->센서 접근하면 자동으로 넘어옴 <키보드입력 금지>

<키보드입력 금지>

(API 데이터 중에 선택) ▼

장치번호
BOX NO
상품명
보관시간
경고시간
위험시간
RAC NO

- 센서장치와 박스를 등록하는 탭.
- 장치가 접근하면 기본으로 제공하는 정보는 자동으로 입력된다.
- RAC번호, BOX번호 등을 입력해야 한다.
- BOX번호는 바코드 스캐너 등으로 BOX번호를 입력받는다.
- 보관시간 등 시간은 내부적으로 분 단위로 환산하고 저장한다.
- 등록 버튼을 누르면
  - 내용을 점검한다.
(잘못된 내용 있으면 메시지를 띄운다.)
  - 준비되면 센서를 초기화하고 BOX를 등록한다.

일 ▼

시간/분

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
내용ok?

전송버튼
확인

내용 확인

Y

센서 초기화

BOX등록
API전송

작업 끝

N

에러 메시지 표시.

## 탭3. 교체 탭

->리스트에서 자동으로 넘어옴 <키보드입력 금지>

->자동으로 넘어옴. <키보드입력 금지>

->리스트에서 자동으로 넘어옴 <키보드입력 금지>

->리스트에서 넘어옴. 분 단위로 표시. 7

->리스트에서 넘어옴. 분 단위로 표시. 3

->리스트에서 넘어옴. 분 단위로 표시. 4

교체장치
BOX NO
상품명
보관시간
경고시간
위험시간
RAC NO

교체

- 센서 교체를 위한 탭.
- 리스트로부터 입력받은 장치의 정보를 보여줌.
- 교체장치 = frserial(바꿀 장치),
덮어 쓸 센서 = toserial(덮어 쓸 장치)
- 전송 과정(교체 버튼 눌리면 실행) :
  1. 설정값 확인
  2. 센서 초기화(frserial의 데이터로 덮어쓰기)
  3. API를 통해서 데이터 교체하기

(대)

->리스트에서

(중)

자동으로

덮어 쓸 센서

(소)

넘어옴

## 탭4. 설정 탭

한국어(Ko-KR) ▼

마스터키 설정
COM 포트

언어설정
Language

연결

자동 검색

- 설정 탭.
- 마스터키 연결 설정, 언어설정을 한다.
- 지원 언어 종류, 그 외의 기본값은 Data.ini으로 저장된다.
- Data.ini는 실행 파일 경로에 있다.

COM5 ▼

## 3. Masterkey Application 사용 방법

## 3-1. 새 박스 등록

※ 센서를
먼저 키는
경우

※ 바코드를 먼저 찍는
경우

시작

시작

센서 전원ON

인식, 프로그램 메시지 띄움.

박스번호 입력

센서 인식 대기
사용자 입력 대기

탭1로 (자동)넘어간 후
사용자 입력 대기
->박스 번호 등록.)

전송버튼

센서 초기화, 박스 등록

끝

입력완성 및
전송버튼

센서 초기화, 박스 등록

끝

## 3-2. 센서 교체

센서교체

교체할 센서 더블클릭

새로운 센서 ON

교체 버튼 클릭

교체 처리

끝

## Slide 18

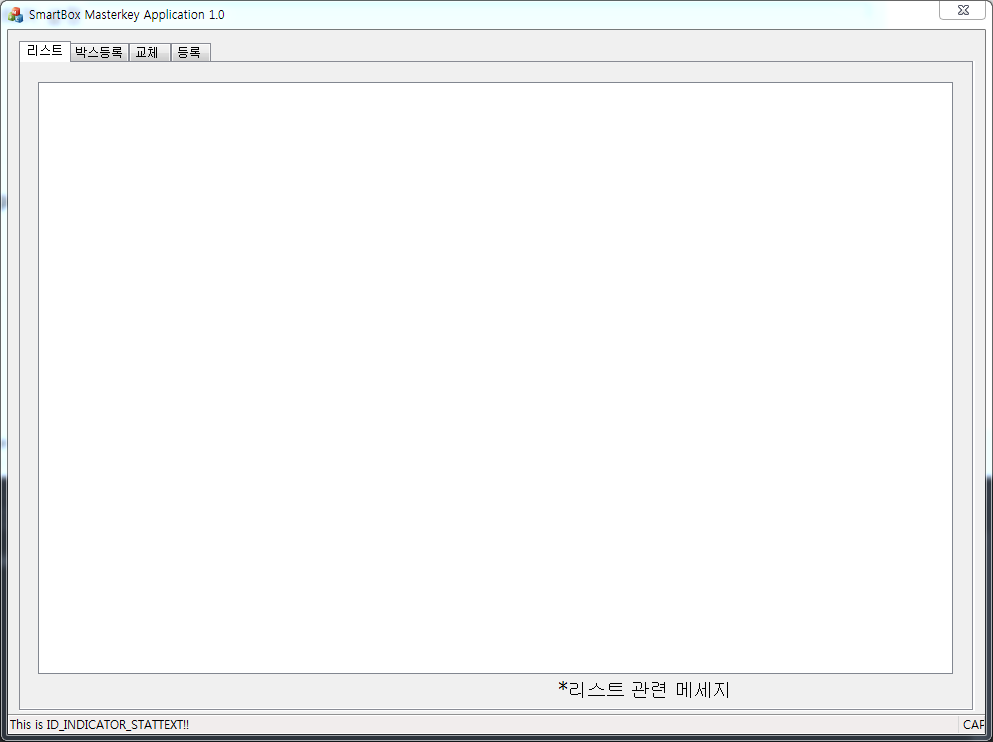
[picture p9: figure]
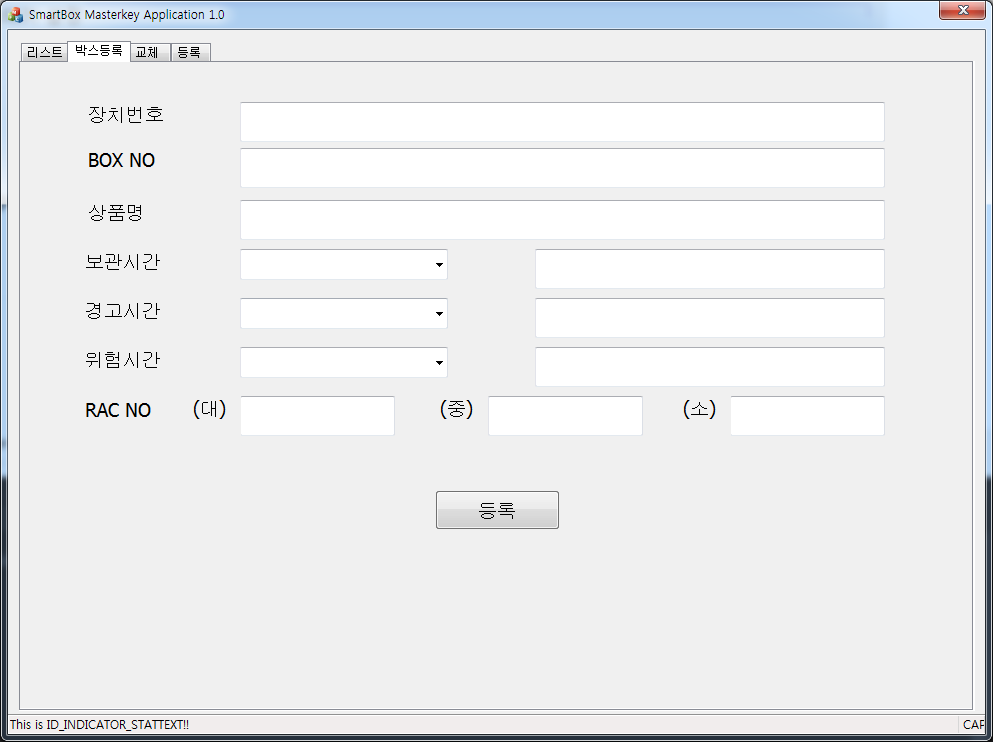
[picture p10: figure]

IDC_COMBO2
IDC_COMBO3
IDC_COMBO4

IDC_STATIC20
IDC_STATIC21
IDC_STATIC22
IDC_STATIC2…
IDC_STATIC29

IDC_LIST1
m_List

IDC_EDIT20
IDC_EDIT21
…
IDC_EDIT25
IDC_EDIT27
…
IDC_EDIT29

IDC_T1CAP

IDC_BUTTON2A

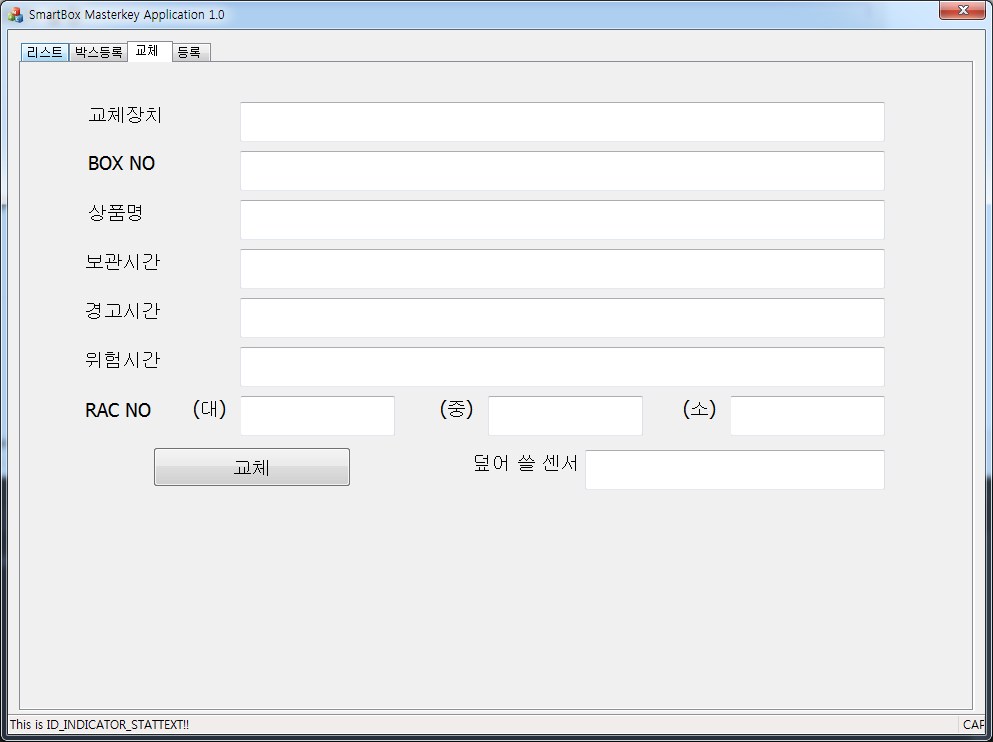
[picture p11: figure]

IDC_STATIC30
IDC_STATIC3…
IDC_STATIC39
IDC_BUTTON3A
IDC_STATIC3B

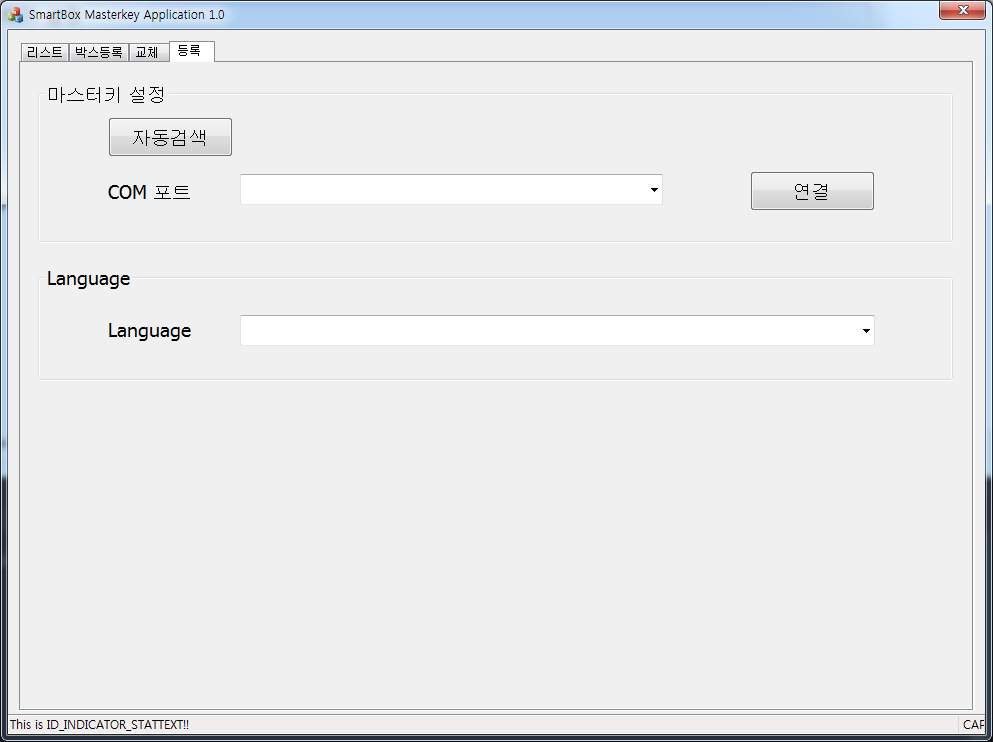
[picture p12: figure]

IDC_EDIT30
…
IDC_EDIT35
IDC_EDIT37
…
IDC_EDIT3A

IDC_STATIC40(Group) IDC_BUTTON40
IDC_STATIC41
IDC_COMBO40
IDC_BUTTON41
IDC_COMBO41

## 언어 설정

지원하는 언어에 따라 폴더명,파일명을 다르게 저장한다.
한국어 -> ko-KR -> ko-KR\ko-KR.lng

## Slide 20

감사합니다.

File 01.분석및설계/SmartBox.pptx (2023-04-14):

## SmartBox

2020-02-12
박준서

## Server 구성도 ( 설치 내용 )

WebSocket Server

InBound

OutBound

80890

80890

SmartBoxMonitoringCoreServerDemon
^D:\SmartBox\MonitoringCoreServerDemon\netcoreapp3.0\SmartBoxMonitoringCoreServerDemon.exe
, …

SERVER

192.168.0.100

WEB

Demon 프로그램 감시자

http://192.168.0.100:20130/

Api

InBound

OutBound

20130

20130

메모리DB(Port 6379)
Redis

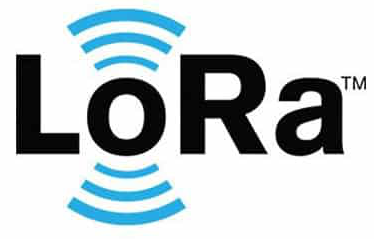
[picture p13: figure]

Api

MariaDB(Port 3306)

WEB Server
: SmartBoxWebMonitoring

http://192.168.0.100:80880/

InBound

80880

WZMSWebMonitoring

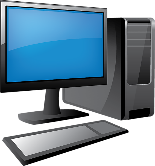
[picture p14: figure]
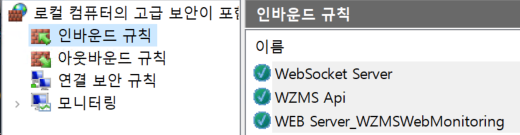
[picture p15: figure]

센싱Data

ws://192.168.0.100:80990/

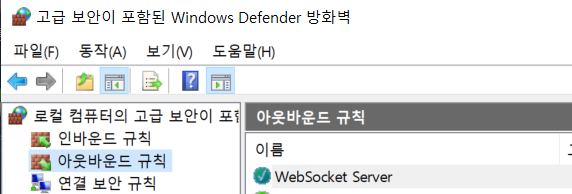
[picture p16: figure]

2020-02-02
박준서

## Flow 구성도

racno = ll,mm,ss
/api/sbd/…rac

관리 사무실

API 정보리스트
/api/slr/센서리스트
/api/sys/
/api/IFO/box
/god
/zon
/cus
/equ

교환flg = 0

센서On

창고

RAC등록 / 이동

RAC

RacNo, sdate(시작일자)
[In Touch LCD] /api/wei/u2
또는 racno = ll,mm,ss
/api/sbd/…rac

장비등록
idx장비, SerialNo, 장비명,appkey, idxClient

SerialNo

종료

장비-SPEC
idxSpec, idx장비, idxClient, idxRef

기초정보 ▲

마스터키

workzone_equip
work_zone_num, equip_sn, BoxCode, idxClient, idxGoods, savetotmin, warningmin, dangermin, RacNo, startdate(for모니터링)

RAC으로 이동 및 보관

START

상태변동 및 센싱
dat,war,dgr,rst

SerialNo 지우기
/api/sbd/…shp

sdate, SerialNo
/api/sbd/…str

workzone_equip
work_zone_num, equip_sn, BoxCode, idxClient, idxGoods, savetotmin, warningmin, dangermin, RacNo, startdate

장비SPEC등록
idxSpec, idxClient, max/min, waring, danger Fr/To

Workzone_equip
지우기
/api/sbd/…shp

시작

상품등록
idxGoods, idxClient, 상품명, 보존기한, idx거래처

Shp(출하)

센서 초기화

API

센서교체
(선택)frEquip_sn, toEquip_no, work_zone_num, idxClient, chgDate

마스터키

WE 등록 /api/WEI/…

[v]FrSerialno을 toSerialno로 변경 ->serialno교체
/api/CHG/fr^to -> workzone_equip에서도 수정

RacNo, sdate(시작일자)
[In Touch LCD] /api/wei/u2
또는 racno = ll,mm,ss
/api/sbd/…rac

SensingData
Sdate, SerialNo, idxClient, work_zone_num, lastStatus, 센싱값

거래처등록
idxCust, idxClient, 거래처명, 주소, 담당자

FrSerialNo장비 초기화
(가능하면)

센서교체

~~RacNo~~
~~,~~ ~~startdate~~~~(~~~~시작일자~~~~)~~

창고등록
work_zone_num, idxClient, 창고명, 담당자, 주소

기초정보(fr정보) ▼

Box등록
idxBox, BoxCode, idxClient,

to센서On

교환flg = 1

RAC 등록 / 이동

테이블, 화면

## Flow 구성도 : 출하

관리 사무실

창고

장비등록
idx장비, SerialNo, 장비명,appkey, idxClient

종료

장비-SPEC
idxSpec, idx장비, idxClient, idxRef

RAC으로 이동 및 보관

workzone_equip
work_zone_num, equip_sn, BoxCode, idxClient, idxGoods, savetotmin, warningmin, dangermin, RacNo, startdate

장비SPEC등록
idxSpec, idxClient, max/min, waring, danger Fr/To

workzone_equip
work_zone_num, equip_sn, BoxCode, idxClient, idxGoods, savetotmin, warningmin, dangermin, RacNo, startdate(for모니터링)

Workzone_equip
지우기
/api/sbd/…shp

시작

상품등록
idxGoods, idxClient, 상품명, 보존기한, idx거래처

Shp(출하)

센서 초기화

SerialNo 지우기
/api/sbd/…shp

API

SensingData
Sdate, SerialNo, idxClient, work_zone_num, lastStatus, 센싱값

거래처등록
idxCust, idxClient, 거래처명, 주소, 담당자

창고등록
work_zone_num, idxClient, 창고명, 담당자, 주소

Box등록
idxBox, BoxCode, idxClient,

테이블, 화면

## Flow 구성도 : 창고에서 센서 교체

관리 사무실

창고

RAC

장비등록
idx장비, SerialNo, 장비명,appkey, idxClient

종료

장비-SPEC
idxSpec, idx장비, idxClient, idxRef

RAC으로 이동 및 보관

workzone_equip
work_zone_num, equip_sn, BoxCode, idxClient, idxGoods, savetotmin, warningmin, dangermin, RacNo, startdate

장비SPEC등록
idxSpec, idxClient, max/min, waring, danger Fr/To

workzone_equip
work_zone_num, equip_sn, BoxCode, idxClient, idxGoods, savetotmin, warningmin, dangermin, RacNo, startdate(for모니터링)

센서교체
(선택)frEquip_sn, toEquip_no, work_zone_num, idxClient, chgDate

마스터키

시작

상품등록
idxGoods, idxClient, 상품명, 보존기한, idx거래처

API

FrSerialno을 toSerialno로 변경 ->serialno교체
(100~119)/api/CHG/fr^to -> workzone_equip에서도 수정

<flow> 리턴 : v_RESULT
1. Fr와 To가 구매품(Equipment)인가? 아니면 04, 07 리턴
2. To가 사용중인가 ? (sensingdata) 사용중 17 리턴
3. Fr이 사용중(sensingdata)이 아닌가 ? 40 리턴
4. (1) sensingdata : update Fr -> To
(2) workzone_equip에 To가 있다면 삭제하고 workzone_equip : update fr -> To
(3) 없다면 Insert Fr -> To 하고 Fr 지운다.
5. 정상완료면 1 리턴

SensingData
Sdate, SerialNo, idxClient, work_zone_num, lastStatus, 센싱값

거래처등록
idxCust, idxClient, 거래처명, 주소, 담당자

FrSerialNo장비 초기화
(가능하면)

센서교체

창고등록
work_zone_num, idxClient, 창고명, 담당자, 주소

기초정보(fr정보) ▼

Box등록
idxBox, BoxCode, idxClient,

to센서On

교환flg = 1

테이블, 화면

## Flow 구성도 : 창고에서 상품-BOX-센서(Workzone Equip) 등록, Rac이동후 시작

관리 사무실

창고

RAC등록 / 이동

RAC

RacNo, sdate(시작일자)
[In Touch LCD]
(890 ~ 909)/api/wei/u2^idxWE^RacNo^startdate
2020-03-31
또는 racno = ll,mm,ss
/api/sbd/…rac_lA^mA-3^sA-3-1

sdate, SerialNo
/api/sbd/…str_dt20200219104338

장비등록
idx장비, SerialNo, 장비명,appkey, idxClient

종료

장비-SPEC
idxSpec, idx장비, idxClient, idxRef

workzone_equip
work_zone_num, equip_sn, BoxCode, idxClient, idxGoods, savetotmin, warningmin, dangermin, RacNo, startdate(for모니터링)

START

workzone_equip
work_zone_num, equip_sn, BoxCode, idxClient, idxGoods, savetotmin, warningmin, dangermin, RacNo, startdate

장비SPEC등록
idxSpec, idxClient, max/min, waring, danger Fr/To

시작

상품등록
idxGoods, idxClient, 상품명, 보존기한, idx거래처

WE등록 /api/WEI/equip_sn, BoxCode, idxGoods, savetotmin, warningmin, dangermin
, RacNo, startdate [단, No Touch LCD]
(890 ~ 909)/api/wei/in^idxClient^work_zone_num^equip_sn^boxcode
(890 ~ 909)/api/wei/u1^idxWE^idxGoods^savetotmin^warningtotmin^dangertotmin^memo
(890 ~ 909)/api/wei/u2^idxWE^RacNo^startdate
2020-03-31

API

SensingData
Sdate, SerialNo, idxClient, work_zone_num, lastStatus, 센싱값

거래처등록
idxCust, idxClient, 거래처명, 주소, 담당자

창고등록
work_zone_num, idxClient, 창고명, 담당자, 주소

센서교체

Box등록
idxBox, BoxCode, idxClient,

RAC 등록 / 이동

RacNo, sdate(시작일자)
[In Touch LCD]
(890 ~ 909)/api/wei/u2^idxWE^RacNo^startdate
2020-03-31
또는 racno = ll,mm,ss
/api/sbd/…rac_lA^mA-3^sA-3-1

테이블, 화면

## Flow 구성도 : 기초정보 등록

API 정보리스트
/api/IFO/
Request : Packet암호화(100~119)(box^idxClient^work_zone_num^) -- idxBox, BoxCode
Return : DataTable(박스정보)
Request : Packet암호화(100~119)(god^idxClient^^) -- idxGoods, GoodsName
Return : DataTable(상품정보)
Request : Packet암호화(100~119)(zon^idxClient^^) -- work_zone_num, work_zone_name
Return : DataTable(창고정보)
Request : Packet암호화(100~119)(cus^idxClient^^) -- idxClient, ClientName
Return : DataTable(거래처정보)
Request : Packet암호화(100~119)(equ^idxClient^work_zone_num^) -- idxEquip, equip_name
Return : DataTable(장비정보)
Request : Packet암호화(100~119)(eq2^idxClient^work_zone_num^) -- idxEquip, equip_sn
Return : DataTable(장비정보)
-> json

관리 사무실

장비등록
idx장비, SerialNo, 장비명,appkey, idxClient

장비-SPEC
idxSpec, idx장비, idxClient, idxRef

장비SPEC등록
idxSpec, idxClient, max/min, waring, danger Fr/To

시작

상품등록
idxGoods, idxClient, 상품명, 보존기한, idx거래처

상품정보 등록 (100~119)/api/gds/in^idxClient^BoxCode
상품정보 리스트 (100~119)/api/gds/list^idxClient^
상품정보 상세 (100~119`)/api/gds/list^idxClient^BoxCode

거래처등록
idxCust, idxClient, 거래처명, 주소, 담당자

창고등록
work_zone_num, idxClient, 창고명, 담당자, 주소

Box등록
idxBox, BoxCode, idxClient,

박스정보 등록 (100~119)/api/box/in^idxClient^BoxCode^RFID
박스정보 리스트 (100~119)/api/box/list^idxClient^
박스정보 상세 (100~119)/api/box/list^idxClient^BoxCode

테이블, 화면

## 데이터 흐름도

- key db.StringGet(key)
0, sbkkb000000002racbmm -> 2020-02-19 20:23:56_sbkkb000000002_rac_mm_0_3_97_B
1, sbkkb000000002dgrbtp -> 2020-02-19 20:27:12_sbkkb000000002_dgr_tp_0_3_91_24.1
2, sbkkb000000002datbtp -> 2020-02-19 20:24:09_sbkkb000000002_dat_tp_0_3_97_23.6
3, sbkkb000000002shpbtp -> 2020-02-18 20:10:10_sbkkb000000002_shp_tp_0_3_94_24.7
4, sbkkb000000001racbll -> 2020-02-19 20:21:57_sbkkb000000001_rac_ll_0_3_95_A
5, sbkkb000000002datbhu -> 2020-02-19 20:24:09_sbkkb000000002_dat_hu_0_3_97_78.1
6, sbkkb000000001rstbtp -> 2020-02-19 20:23:38_sbkkb000000001_rst_tp_0_3_92_24.6
7, sbkkb000000001dgrbtp -> 2020-02-19 20:23:06_sbkkb000000001_dgr_tp_0_3_93_25.1
8, sbkkb000000002shpbhu -> 2020-02-18 20:10:10_sbkkb000000002_shp_hu_0_3_94_73.3
9, sbkkb000000002racbss -> 2020-02-19 20:23:56_sbkkb000000002_rac_ss_0_3_97_13
10, sbkkb000000001shpbtp -> 2020-02-18 20:09:01_sbkkb000000001_shp_tp_0_3_92_24.7
11, sbkkb000000001warbhu -> 2020-02-19 20:22:23_sbkkb000000001_war_hu_0_3_93_68.9
12, sbkkb000000002warbhu -> 2020-02-19 20:24:31_sbkkb000000002_war_hu_0_3_88_66.9
13, sbkkb000000001datbtp -> 2020-02-19 20:22:12_sbkkb000000001_dat_tp_0_3_95_24.5
14, sbkkb000000001dgrbhu -> 2020-02-19 20:23:06_sbkkb000000001_dgr_hu_0_3_93_71.3
15, sbkkb000000001rstbhu -> 2020-02-19 20:23:38_sbkkb000000001_rst_hu_0_3_92_73.3
16, sbkkb000000001warbtp -> 2020-02-19 20:22:23_sbkkb000000001_war_tp_0_3_93_24.5
17, sbkkb000000002dgrbhu -> 2020-02-19 20:27:12_sbkkb000000002_dgr_hu_0_3_91_61.3
18, sbkkb000000001racbmm -> 2020-02-19 20:21:57_sbkkb000000001_rac_mm_0_3_95_F
19, sbkkb000000001racbss -> 2020-02-19 20:21:57_sbkkb000000001_rac_ss_0_3_95_1
20, sbkkb000000002warbtp -> 2020-02-19 20:24:31_sbkkb000000002_war_tp_0_3_88_26.5
21, sbkkb000000002racbll -> 2020-02-19 20:23:56_sbkkb000000002_rac_ll_0_3_97_B
22, sbkkb000000001datbhu -> 2020-02-19 20:22:12_sbkkb000000001_dat_hu_0_3_95_68.9
23, sbkkb000000002rstbhu -> 2020-02-18 20:10:01_sbkkb000000002_rst_hu_0_3_95_78.3
24, sbkkb000000002rstbtp -> 2020-02-18 20:10:01_sbkkb000000002_rst_tp_0_3_95_26.6
25, sbkkb000000001shpbhu -> 2020-02-18 20:09:01_sbkkb000000001_shp_hu_0_3_92_73.3

API

SmartBoxMonitoringCoreServerDemon

- pair.Key pair.Value [0] [1] [2] 3 4 5 6 [7]
sbkkb000000001datbhu = 2020-02-19 20:22:12_sbkkb000000001_dat_hu_0_3_95_68.9
sbkkb000000001datbtp = 2020-02-19 20:22:12_sbkkb000000001_dat_tp_0_3_95_24.5
sbkkb000000001warbhu = 2020-02-19 20:22:23_sbkkb000000001_war_hu_0_3_93_68.9
sbkkb000000001warbtp = 2020-02-19 20:22:23_sbkkb000000001_war_tp_0_3_93_24.5
sbkkb000000001dgrbhu = 2020-02-19 20:23:06_sbkkb000000001_dgr_hu_0_3_93_71.3
sbkkb000000001dgrbtp = 2020-02-19 20:23:06_sbkkb000000001_dgr_tp_0_3_93_25.1
sbkkb000000001rstbhu = 2020-02-19 20:23:38_sbkkb000000001_rst_hu_0_3_92_73.3
sbkkb000000001rstbtp = 2020-02-19 20:23:38_sbkkb000000001_rst_tp_0_3_92_24.6
sbkkb000000002datbhu = 2020-02-19 20:24:09_sbkkb000000002_dat_hu_0_3_97_78.1
sbkkb000000002datbtp = 2020-02-19 20:24:09_sbkkb000000002_dat_tp_0_3_97_23.6
sbkkb000000002warbhu = 2020-02-19 20:24:31_sbkkb000000002_war_hu_0_3_88_66.9
sbkkb000000002warbtp = 2020-02-19 20:24:31_sbkkb000000002_war_tp_0_3_88_26.5
sbkkb000000002dgrbhu = 2020-02-19 20:27:12_sbkkb000000002_dgr_hu_0_3_91_61.3
sbkkb000000002dgrbtp = 2020-02-19 20:27:12_sbkkb000000002_dgr_tp_0_3_91_24.1

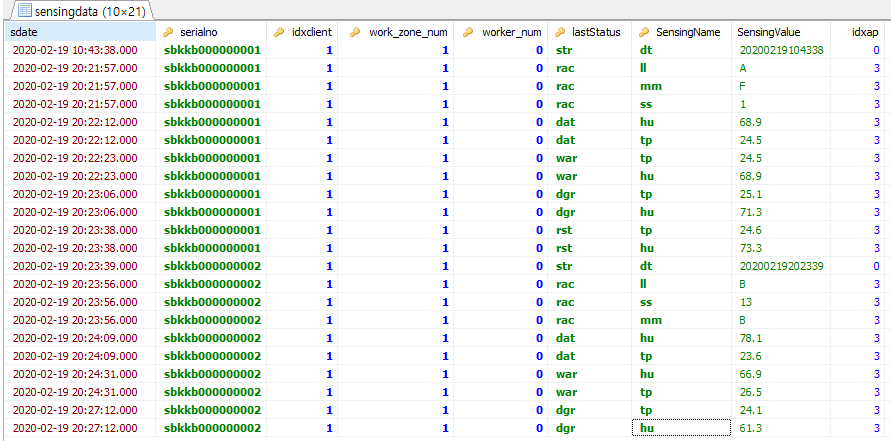
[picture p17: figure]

## 데이터 흐름도

//Box의 입고기간에 따른 알람상태 : sdate, serialno, alertInsaveterm, stype, svalue, alertcode, unit, status, idxAp, BT, StartDt, WarningDt, DangerDt, LastDt, alertstatus, worker_num | ...

3000,100,300^1000,30,50^500,10,25^200,5,20
^2020-02-19 20:22:12, sbkkb000000001, hu, 68.9, w, %, dat, 3, 95, 0 |
2020-02-19 20:22:12, sbkkb000000001, tp, 24.5, n, ℃, dat, 3, 95, 0 |
2020-02-19 20:22:23, sbkkb000000001, hu, 68.9, n, %, war, 3, 93, 0 |
2020-02-19 20:22:23, sbkkb000000001, tp, 24.5, n, %, war, 3, 93, 0 |
2020-02-19 20:23:06, sbkkb000000001, hu, 71.3, d, %, dgr, 3, 93, 0 |
2020-02-19 20:23:06, sbkkb000000001, tp, 25.1 , n, %, dgr, 3, 93, 0 |
2020-02-19 20:23:38, sbkkb000000001, hu, 73.3, w, %, rst, 3, 92, 0 |
2020-02-19 20:23:38, sbkkb000000001, tp, 24.6 , n, %, rst, 3, 92, 0 |
2020-02-19 20:24:09, sbkkb000000002, hu, 78.1, w, %, dat, 3, 97, 0 |
2020-02-19 20:24:09, sbkkb000000002, tp, 23.6 , n, %, dat, 3, 97, 0 |
2020-02-19 20:24:31, sbkkb000000002, hu, 66.9, d, %, war, 3, 88, 0 |
2020-02-19 20:24:31, sbkkb000000002, tp, 26.5 , n, %, war, 3, 88, 0 |
2020-02-19 20:27:12, sbkkb000000002, hu, 61.3, n, %, dgr, 3, 91, 0 |
2020-02-19 20:27:12, sbkkb000000002, tp, 24.1 , n, %, dgr, 3, 91, 0
^ sbkkb000000001, 2020-02-19 10:43:38, 2020-02-23 10:43:38, 2020-02-24 10:44:38, 2020-02-26 10:43:38, n, 0 |
sbkkb000000002, 2020-02-19 10:43:38, 2020-02-23 10:43:38, 2020-02-24 10:44:38, 2020-02-26 10:43:38, n

Monitoring Web Site

## 모니터링 화면 흐름도

시작

로그앤

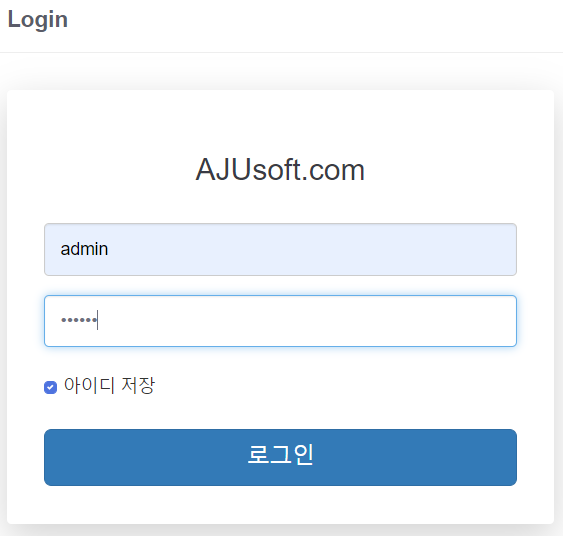
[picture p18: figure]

메인메뉴

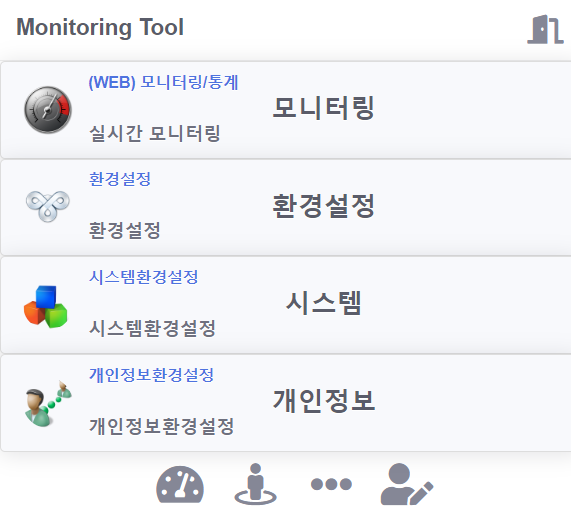
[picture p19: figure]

창고리스트

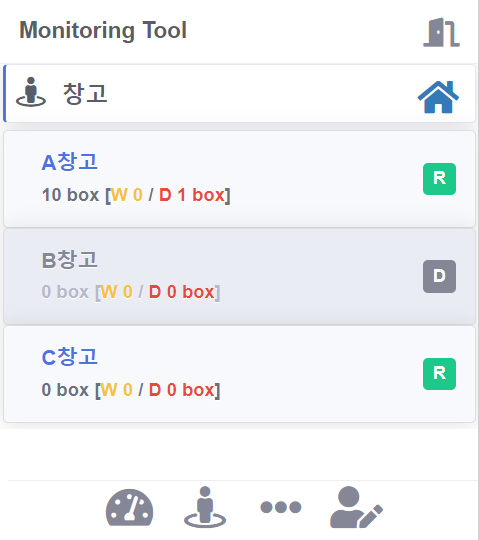
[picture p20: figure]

wzno

ClassL 리스트

ClassM 리스트

ClassS 리스트

모니터링

테이블, 화면

## 시스템 구성도

## 시스템 구성도 : 흐름도

WZMSlocaldb

<모니터링, Socket통신>
로컬모니터링PCAddr
, 로컬모니터링Port

<Base64 -> Packet암호화(100~119)>

/api/itro/

Req : idxClient

Rtn : Client Info, CloudAddr

/api/lgn/1^admin^112233

<Base64 -> Packet암호화(100~119)>

/api/lgn/

Req : idxClient^id^PWD

Rtn : token

<Packet암호화(890~909)>

1. wzkkb0000000011000077/tp36.3^hu56^ox20.30^ps1018 : LAN 48
2. Data Format : json

WZMS Demon v.2.0

마스터키 실행

(Win App)
모니터링 실행

(Web)
관리하기

예시) /api/wzl/1^59d174ff86664c8bb5933c077ce0c5d0

/api/wzl/

Req : idxClient, token

Rtn : Workzone list(진행중만) = [{num, name},…]

< Base64 -> Packet암호화(100~119)>

< Base64 -> Packet암호화(100~119)>

/api/apl/

Req : idxClient, token

Rtn : APList = [{idxap, apssid, appwd(앱키)},…]

<appwd는 Packet암호화(890~909)>

< Base64 -> Packet암호화(100~119)>

/api/snn/

Req : idxClient, token

Rtn : Sensor별 부여번호 List = [{serialtype, usednos},…]

< Base64 -> Packet암호화(100~119)>

/api/rvs/

Req : idxClient, token

Rtn : 센서별 센싱보정 값 List = [{equip_sn, revision value},…]

/api/slr/

Req : idxClient, admin(->Lora Gateway에서 보내기 때문에 아무값이나 무관)

Rtn : 센서별 ID 값 List = [{equip_sn, idx},…]

< Base64 -> Packet암호화(100~119)>

/api/sys/

Req : idxClient, token

Rtn : System Info = [{SystemNameInit, CloudAddr, PCIPAddr, LocalPCPort, 센싱타임(초)},…]

예시) wzkk http (http://localhost:2013/api/):// (http://localhost:2013/api/)localhost:2013/api/ssd/ 192.168.0.9 2013 1

Tray
VC++ App

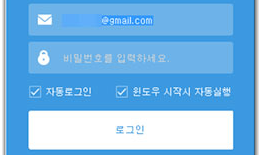
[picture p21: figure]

테이블 config
cloud_webmonitoring_url
cloud_webmanage_url

2019-06-01

/api/alins/

~~<~~~~Base64 ->~~ ~~Packet~~~~암호화~~~~(100~119)>~~

Req : 알람저장 idxClient, wokzone_num
, equip_sn, alerttype, sensortype
, alertvalue, ipaddress

Clouc Web 서버

wzmsdb

알람

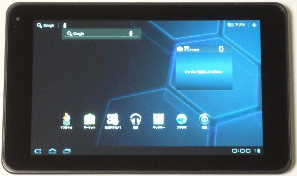
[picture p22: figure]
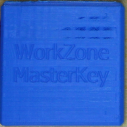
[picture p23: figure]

RcvDemon_z1
measure_data_z1 만 있음

알람

알람 : 문자,SNS

wzmsconfig.ini
- comname : 우리건설
- idxClient : 1

WZMS Masterkey App v.2.0

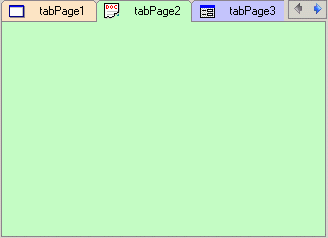
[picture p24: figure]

회사명

작업장

우리건설

AaZ1

동기화

- Workzone list (진행중만)
- APList
- Sensor ID List
- Sensor별 부여번호 List
- System Info

센싱데이터(소켓)

<센서세팅>
- Power ON
- Reset

센싱데이터

On/Reset : local, cloud의
연결을체크하여 연결된 곳에만 보낸다.

/api/ssd/

Req : 패킷 데이터

Rtn : 없음

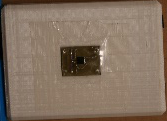
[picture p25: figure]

~~<~~~~Base64 ->~~ ~~Packet~~~~암호화~~~~(100~119)>~~

Rtn : Result=01

Sensor별 부여번호 변경시

/api/snnup/

Req : 변경된 idxClient, Workzone-num, serialtype, usedno

## 시스템 구성도 : 마스터키 전체 흐름도

2019-06-10

1. wzkkb0000000011000077/tp36.3^hu56^ox20.30^ps1018 : LEN 48

<센서세팅>
- Power ON
- Reset

Clouc Web 서버

wzmsdb

/api/sbd/

Req : 패킷 데이터

Rtn : 없음

①

AP_SSID

AP정보가 변경될때 마다 구해 저장한다.

센서 초기에 SN과 함께 lora/wifi 타입을 저장한다

⑥ b = 1
b = 2
h = 4

⑦ Rtn : Result=01

http://192.168.0.9:80/api/snnup/1^1^b^1

http://192.168.0.9:80/api/snnup/1^1^h^4

WZMS Masterkey App v.2.0

회사명

우리건설

AaZ1

동기화

작업장

- Workzone list (진행중만)
- APList
- 센서별 센싱보정 값 List
- 센서별 ID List
- System Info

센싱데이터

④ b = 1
b = 2
h = 4

wzkkb00000001, lora

Wzkkb00000002, wifi

wzkkh00000004, wifi

② serial no : wzkkb00000001, lora

: wzkkb00000002, wifi

: wzkkh00000004, wifi

⑨ APList = [{idxap, apssid, appwd(앱키)},…]

System Info
= [{SystemNameInit, CLOUD주소:포트, 로컬모니터링PCAddr
, 로컬모니터링Port,센싱타임(초) ,센싱보정값},…]

~~LoraWifiType~~ ~~List~~~~에서 자신에게 설정된 값~~~~(~~~~lora~~ ~~/~~~~wifi~~~~)~~~~만 가진다~~~~.~~

Sensor별 부여번호(SUN) = STX+SUN+ENQ+b+US(1F)+1+ETX
Return = STX+RTN+ENQ+SUN+US(1F)+01+ETX

센서고장 처리는?

마스터키 연결체크(ALV) : STX+ALV+ENQ+masterkey+US(1F)+01+ETX
Return = STX+RTN+ENQ+ALV+US(1F)+01+ETX

(SYS)System Info = [{SystemNameInit, CLOUD주소:포트, 로컬모니터링PCAddr
, 로컬모니터링Port,센싱타임(초), ~~기본~~ ~~LoraWifiType~~, 로컬PC 끊김 판단기준, 클라우드 서버 끊김 판단기준, 로컬PC 재시도 주기, 클라우드 서버 재시도 주기},…]

⑧ (APL)APList = [{idxap, apssid, appwd(앱키)},…]

예시 : wzkk, http://localhost:2013/api/ssd/, 192.168.0.9, 2013, AAA1, 1

(RVS)센서별 센싱보정 값 List = [{equip_sn, revision value},…]

(SLR)센서별 ID List = [{equip_sn, idx},…]

③ 저장 : Sensor별 부여번호 List = [{serialtype, usednos,1,2,3,4…},…]
: b = 1,2
: h = 4
<동적생성>

STX = (char)0x02;
ETX = (char)0x03; //End Text [응답용Asc]
EOT = (char)0x04; //End of Text[요구용 Asc]
ENQ = (char)0x05; //Enquire[프레임시작코드]
ACK = (char)0x06; //Acknowledge[응답 시작]
NAK = (char)0x15; //Not Acknoledge[에러응답시작]
RS = (char)0x1E; //record separator
US = (char)0x1F; //(Hx)unit separator
GS = (char)0x1D; //(Hx)group separator
TAB = (char)0x09; //(Hx)horizontal tab

⑤ b = 1,2
h = 4
<동적생성>

Return = STX(2) + RTN + ENQ(5) + ALV + US(1F) + 01 + ETX(3)

(00 – 실패, 01 – 성공)

System Info = STX(2) + SYS + ENQ(5) + {“SystemNameInit” : “wzkk”, ”CloudAddr”: ”http://localhost:2013/api/ssd/”, “PCIPAddr”: “192.168.0.9”
, ”PCPort”: ”2013”, ”SensingTerm” : ”1” , ~~”basic_LoraWifiType”:”wifi~~~~”,~~"GiveupCountS":"2","GiveupCountC":"2","RetryCountS":"9","RetryCountC":"9“} + ETX(3)

APList = STX(2) + APL + ENQ(5) + {“Column명‘s(US(1F)) + Column값 ‘s(US(1F))”} + ETX(3)

## Layout

고용량 배터리 KIT

- [관리 및 통계] Web -

리셋버튼 : 스위치로

- [외부]Sensor 001 -
온도

리셋버튼 : 스위치로

- [내부]작동 기기 -
환기장비 / 조명장비 등

- [WZMSWS]Web Service -
실시간 센서 데이터 수신 및 저장

- [사용권한]Web Service -

wzmsdb

AP
Bluetooth

[기능]
1. 개인별 온도 모니터링 : [내부]Sensor 004 ~ N
2. 작업실 내부 환경 모니터링 : [내부]Sensor 002
3. 외부 환경 모니터링 : [외부]Sensor 001
4. 경고 및 알람 기능
5. 내부완경에 따른 후속장비 제어 : 환기용 모터 작동 등
6. 작업자 / 장비 / 센서 관리

- [모니터링] PC -

- [WSMS Demon] PC -

외부장비 작동

리셋버튼 : 스위치로

- [내부]Sensor 002 -
온도/산소/이산화탄소/공기질

Express_wzmsdb

- [내부]Sensor 004 -
인체 온도

- [내부]Sensor N -
인체 온도

리셋버튼 : 스위치로

## Layout

CLOUD

고용량 배터리 KIT

- [WZMSWS]Web Service -
실시간 센서 데이터 수신 및 저장
ssdt.aspx

- [사용권한]Web Service -

리셋버튼 : 스위치로

- [외부]Sensor 001 -
온도

리셋버튼 : 스위치로

- [내부]작동 기기 -
환기장비 / 조명장비 등

6

wzmsdb

- [관리 및 통계] Web -

AP
Bluetooth

2

send1 : com_biz_num | return1 : token

3

Send2 : com_biz_num, id, pwd | return1 : token

LOCAL

전송 : cloud_wzmsws_url, local_demon_pc_url, com_biz_num

리셋버튼 : 스위치로

- [내부]Sensor 002 -
온도/산소/이산화탄소/공기질

6

1

9

4

- [내부]Sensor 004 -
인체 온도

- [모니터링] PC -
com_biz_num/id/pwd

Express_wzmsdb

- Sensor 초기화 -

실행/종료

5

리셋버튼 : 스위치로

- [내부]Sensor N -
인체 온도

7

8

- [WSMS Demon] PC -

외부장비 작동

## 작업장 안전관리 시스템 System 구성도

대외비(對外秘)

작업 현장

인체온도센서

맨홀

WEB

모니터링 서버

산소센서

모니터링

외부 온도/먼지 센서

2018-09-10
박준서

## Layout

(Windows) Client

(Web) Service Server

(Web Server)
Backup Server

API

Monitoring Server
<port>

- 테이블명 : SensingData
- sp_get_Monitoring_SensingValue2

idxClient, WorkzoneNum, APSSID, idxUser로 조회하여
Sday, stime, serialno, svalue 테이블을 리턴한다.
- 읽어가면서 지운다.

(WIN)모니터링

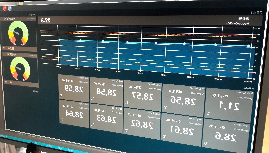
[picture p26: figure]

< Base64 -> Packet암호화(100~119)>

WebSocket('ws://localhost:8000
/idxClient^WorkzoneNum^APSSID
/PacketWatch/')

읽은 후 삭제

wzmslocalwsdb

Insert만

동기화: config, Equipment, ReferenceData, Equip_RefData
: 12시간마다

(WIN)알럼처리
- Fan In / Out 작동
- 경광등 표시

wifi / UTP

모니터링 Web Site

Port=8080

Port=8090

wzmsdb

DB 백업파일

DB 백업파일

- 센싱 : 알람, 경고, EM 데이타
- Masterkey 정보

- 센싱 : 센싱데이터 로그

리턴 : 헬멧,외부, 작업자센서, 외부장비 상태의
sday, stime, ~~idxClient~~~~,~~ ~~WorkzoneNum~~
~~,~~ ~~APSSID~~, SN, svalue, balertcode(n,c,d)
^ alertcode(n,c,d)s
= [경고w/위험d만]alertcode(w,d)s = h2w,o4d,b17w,...

~~<~~ ~~idxClient^WorkzoneNum^APSSID^idxUser~~~~만~~
~~검증위해~~ ~~Base64~~ ~~-> Packet~~~~암호화~~~~(100~119)>~~

센싱데이터
백업파일

-- 등만
gyr=000
Gyr=001=1
gYr=010=10
GYr=011=11
GYR=111
GyR=101
gyR=100
gYR=110

-- 버저 포함
GYR=211
GyR=201
gyR=200
gYR=210

Fan IN

Fan OUT

외부장치

R값이 ---
1 : 등
2 : 등 + 버저(config.alertbuzzer_use = Y/N)

센싱데이터
파일

관리용 Web Site

select * from wzmsdb.alert; -- 알람, 경고, EM 데이타 저장
select * from wzmsdb.SensingData; -- Monitoring Server 전달용. 이전 데이터 삭제
select * from wzmslocalwsdb.SensingData; -- to Text Log 만 저장하고 사용안함

## Layout

(Windows) Client

(Web) Service Server

(Web Server)
Backup Server

API

- 테이블명 : SensingData
- sp_get_Monitoring_SensingValue2

idxClient, WorkzoneNum, APSSID, idxUser로 조회하여
Sday, stime, serialno, svalue 테이블을 리턴한다.
- 읽어가면서 지운다.

센싱데이터
파일

(WIN)모니터링

< Base64 -> Packet암호화(100~119)>

WebSocket('ws://localhost:8000
/idxClient^WorkzoneNum^APSSID
/PacketWatch/')

읽은 후 삭제

메모리 DB

메모리DB_Redis

(WIN)알럼처리
- Fan In / Out 작동
- 경광등 표시

wifi / UTP

모니터링 Web Site

Port=8080

Monitoring Demon Server
<port>

Port=8090

DB 백업파일

리턴 : 헬멧,외부, 작업자센서, 외부장비 상태의
sday, stime, ~~idxClient~~~~,~~ ~~WorkzoneNum~~
~~,~~ ~~APSSID~~, SN, svalue, balertcode(n,c,d)
^ alertcode(n,c,d)s
= [경고w/위험d만]alertcode(w,d)s = h2w,o4d,b17w,...

~~<~~ ~~idxClient^WorkzoneNum^APSSID^idxUser~~~~만~~
~~검증위해~~ ~~Base64~~ ~~-> Packet~~~~암호화~~~~(100~119)>~~

DB 백업파일

센싱데이터
백업파일

-- 등만
gyr=000
Gyr=001=1
gYr=010=10
GYr=011=11
GYR=111
GyR=101
gyR=100
gYR=110

-- 버저 포함
GYR=211
GyR=201
gyR=200
gYR=210

Fan IN

Fan OUT

외부장치

R값이 ---
1 : 등
2 : 등 + 버저(config.alertbuzzer_use = Y/N)

wzmsdb

관리용 Web Site

- 센싱 : 알람, 경고, EM 데이타
- Masterkey 정보

select * from wzmsdb.alert; -- 알람, 경고, EM 데이타 저장
select * from wzmsdb.SensingData; -- Monitoring Server 전달용. 이전 데이터 삭제
select * from wzmslocalwsdb.SensingData; -- to Text Log 만 저장하고 사용안함

## Flow별 상세설명

순 | 센서 | 로컬 | 서버 | 비고
1 | | 회사 사업자번호를 모니터링 PC에 처음 세팅할 때 WebConfig에 지정 <add key="com_biz_num" value="00000000000000000001-002"/> - Local DB의 테이블config -> ClientCode : 사업자번호와 com_name : 사업자명 : 사업자번호를 등록해야 한다. | | 모니터링 PC세팅
2 | | [모니터링] PC-[Workzone프로그램] com_biz_no 암호와 해서 전송 토큰(1) 전역변수에 저장 | [사용권한]Web Service 토큰{1) 암호화해서 생성(token) 및 전송(암호화) - 토큰=yyyyMMddHHmmss.idxToken를 암화화 한다. | com_biz_no는 12345678901234567890-000 = 사업자번호-사용번호
3 | | [모니터링] PC-[Workzone프로그램] com_biz_num, id, pwd 암호화 해서 전송 토큰(1)과 받은 토큰(2)를 비교하여 동일하면 프로그램 실행 | [사용권한]Web Service com_biz_num를 이용하여 토큰 조회하여 토큰(2) 전송(암호화)
4 | | [모니터링] PC-[Workzone프로그램] 작업장/장비/작업자 정보를 로컬DB에 등록 및 전송 | [사용권한]Web Service 받은 정보를 DB에 저장
5 | 센서 초기화 | [모니터링] PC-[Workzone프로그램] - 데이터 저장 | [WZMSWS]Web Service - 데이터 저장 | 뒤 페이지에 상세 설명
6 | | [모니터링] PC-[Workzone프로그램] 모니터링 시작 -> [WSMS Demon] 프로그램 실행 네트워크 연결안 될 경우 저장후 연결되면 일괄전송 | | BigData 수집목적
7 | 센서데이터 송신 | [모니터링] PC-[WSMS Demon] 프로그램 - 센서 데이터 수신 후 저장 | [WZMSWS]Web Service - 센서 데이터 수신 후 저장 | 센서 데이터 수신시 알람체크
8 | 외부 장시 ON | [모니터링] PC-[WSMS Demon] 프로그램에서 알람발생 - alert에 저장 - 위험 알람 처리 : 외부장치 ON, 화면에 메시징 | [WZMSWS]Web Service 알람발생 - alert/발송메시지테이블(sendmsg)에 저장 - 위험 알람 처리 : 담당자에게 Email, SMS, 카톡 알림톡 전송
9 | 외부 장시 OFF | [모니터링] PC-[WSMS Demon] 프로그램에서 알람해지 - 위험 알람 처리 : 외부장치 ON, 화면에 메시징 해지 | [WZMSWS]Web Service 알람해지 - 위험 알람 처리 : 담당자에게 Email, SMS, 카톡 알림톡 전송
10 | OFF | 종료 및 대기 - [모니터링] PC-[Workzone프로그램] 종료 및 대기 - [WSMS Demon] 프로그램 종료 및 대기 | | 작업 종료시 OFF 작업 대기시 센서만 OFF

## 센서/외부기기 초기화

4

순 | 센서 | 로컬 | 서버 | 비고
1 | 서버 웹주소 ([WZMSWS]Web Service) : cloud_wzmsws_url | | 센서 데이터 수신 | [POST]http://ip_address/reset curl=yyyyMMddHHmmss
2 | 로컬 PC IP주소 ([WSMS Demon] PC) : local_demon_pc_url | 센서 데이터 수신 | | lsvrip=
3 | com_biz_num : 센서 사용처 사업자 등록번호, 없으면 생성 후 등록 | | | cnum=
4 | Ap addresss : AP_Address | | | apip=
5 | 시간 세팅 : 로컬서버PC의 시간과 센싱데이터 시간의 차가 3초 차가 나면 전송 | | | [POST]http://ip_address/setdt dt=yyyyMMddHHmmss
| Serial no : wzms-kor-a0000,1 (변경) wzkkb000000001 : 공장 출고시 1회 세팅 | | | 센서 패킷에 포함 h = 헬멧형, b=몸 부착형, o=장소형, a=알람장비, f=환풍기, l=램프, …
| SSID를 Serial no로 세팅한다. : 공장 출고시 1회 세팅
| 센서의 IP 주소 : 기본 세팅 후 현장에서 변경가능
| 패킷 구조 //serial no(15) /yyyyMMddHHmmss/com_biz_no(20-3) /밧데리잔량Battery charge/에러율% /센서값(-일때만 부호있음)… //[0] [1] [2] [3] [4] [5] wzms-kor-a00001/20180724205211/00000000001298124333-001/bt00/er00^00^00^00^00^00^00^00^00/tp-45.3^ox12.4^co33.3^du456^hu120^ni66.4^uv88^pp20^hd56^ps1034 h = 헬멧형, b=몸 부착형, o=외부 장소형, a=알람장비, f=환풍기, l=램프, … xSpace.wzms.biz.Lib.emEquipType 변경 : wzms_ko-KR_b00000001/idxClient^wokzone_num/AP_SSID/bt86/er00/wzms^tp26.76 sn /검증용 2. 변경 : wzms_ko-KR_b00000001/idxClient^wokzone_num/AP_SSID/bt86/wzms^tp26.76 : 에러율 삭제 : LAN 77 sn /검증용 1.3. 변경 : wzb00000001/10000^10000/aa1/77/tp36.3^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
소켓통신 | 전체 패킷 구조 : STX + Serial no + SOH + 패킷 + ETX '\x02' + Serial no + '\x01' + 패킷 + '\x03'

## Layout

리셋버튼 : 스위치로

- [외부]Sensor 001 -
온도

Serial no : 공장 출고시 1회 세팅
SSID를 Serial no로 세팅한다. : 공장 출고시 1회 세팅
센서의 IP 주소 : 기본 세팅 후 현장에서 변경가능

서버 웹주소 ([WZMSWS]Web Service) : cloud_wzmsws_url
로컬 PC IP주소 ([WSMS Demon] PC) : local_demon_pc_url
com_biz_num : 센서 사용처 사업자 등록번호, 없으면 생성 후 등록
Ap addresss : AP_Address
시간 세팅 : 로컬서버PC의 시간과 센싱데이터 시간의 차가 3초 차가 나면 전송

AP
Bluetooth

- [내부]작동 기기 -
환기장비 / 조명장비 등

리셋버튼 : 스위치로

- [내부]Sensor 002 -
온도/산소/이산화탄소/공기질

- [내부]Sensor 004 -
인체 온도

리셋버튼 : 스위치로

- [모니터링] PC -
com_biz_num/id/pwd

- [내부]Sensor N -
인체 온도

리셋버튼 : 스위치로

## Local [모니터링] PC Flow

순 | 시점 | 위치 | 설정 | 설정 내용 | 비고
1 | 공장출시 때 | Web.conifg Client테이블에 정의 | idxClient Connect string 에러 저장위치 com_biz_num 사용언어 설정 | <add key="idxClient" value="1"/> <add key="WZMS" value="암호화한 Connect string정보"/> <add key="ErrowMsgSavePhysicalPathOnly" value="D:\DEV_WZMS\Log\"/> - Client테이블 : client biz num, langver 등 기본정보 세팅 User테이블 : admin, 최초비번 세팅 admin@2013 | 최초 PG 보급시 기록
| 공장출시 때 | 로컬ExpressDB.config | | sensortype, nation, language, caption_lang_columns
2 | 프로그램 최초 실행 때 | 로컬ExpressDB.config | | 회사명, 회사 전화번호, 로그 저장폴더, 시스템 언어, System Version , Cloud 웹서비스 주소, 로컬 PC IP Address, 로컬 AP IP Address , Sensor 데이터 저장주기 | 프로그램 실행 후 로그인 창 “기초정보 설정“ 탭에서 저장 - 변경은 환경설정에서한다.
3 | 로그인 | 웹서비스 호출 | [모니터링] PC-[Workzone프로그램] com_biz_no 암호와 해서 전송 토큰(1) 전역변수에 저장 | [사용권한]Web Service 토큰{1) 암호화해서 생성(token) 및 전송(암호화) - 토큰=yyyyMMddHHmmss.idxToken를 암화화 한다.
4 | 로그인 | 웹서비스 호출 | [모니터링] PC-[Workzone프로그램] com_biz_num, id, pwd 암호화 해서 전송 토큰(1)과 받은 토큰(2)를 비교하여 동일하면 프로그램 실행 | [사용권한]Web Service com_biz_num를 이용하여 토큰 조회하여 토큰(2) 전송(암호화)
5 | 프로그램 구동

## 기본코드

1. Serial No = xSpace.wzms.biz.Lib.emEquipType
- HelmetType = 0, //h 헬멧형…wzms-kor-h00001
- BodyType = 1, //b …wzms-kor-b00001
- OutsideType = 2, //o …wzms-kor-o00001
- AlarmType = 3, //a …wzms-kor-a00001
- FanType = 4, //f …wzms-kor-f00001
- LampType = 5, //l …wzms-kor-l00001
- Etc = 6, //e …wzms-kor-e00001
2. Sensor Type = xSpace.wzms.biz.Lib.emSensorType -> 테이블 measure_data_*
- CO 이산화탄소 : PPM, 0 ~ 5000 ?
4. 인체에 미치는 영향
4-1. 농도별(ppm기준) 인체에 미치는 영향
농도(ppm)
영향
~450 : 건강한 환기 관리가 된 레벨
~700 : 장시간 있어도 건강에 문제가 없는 실내 레벨
~1000 : 건강 피해는 없지만 불쾌감을 느끼는 사람이 있는 레벨
~2000 : 졸림을 느끼는 등 컨디션 변화가 나오는 레벨
~3000 : 어깨 결림이나 두통을 느끼는 사람이 있는 등 건강 피해가 생기기 시작하는 레벨
3000~ : 두통, 현기증 등의 증상이 나오고, 장시간으로는 건강을 해치는 레벨
※ 미국의 경우 실내환기조건을 CO2를 기준으로 2000ppm을 권장하고 있으나 우리나라와 일본의 경우는 1000ppm을 기준으로 하고 있음
※ 우리나라 다중 이용시설 실내 공기질 관리법에서 실내는 1000ppm이하로 유지토록 권장
ASHRAE 미국냉동공조협회(세계 여러나라에서 이 규정을 활용)
- DU 먼지농도 : ㎍/㎥
주의보 미세먼지(PM10) 시간당 평균 농도 150㎍/㎥ 이상(2시간 지속)
경 보 미세먼지(PM10) 시간당 평균 농도 300㎍/㎥ 이상(2시간 지속)
- HD 수소 : pH
- HU 습도 : %
- NI 질소 : %
- OX 산소 : %
- PP 맥박수 : BPM
- TP 온도 : ℃
- UV 자외선 %
- PS 기압 : hPa
- ER 에러율
- EM 위급버튼 클릭(센서)

ì ¨ë ì ¸ì²´ ì í ¥ì ë í ì ´ë¯¸ì§ ê² ì ê²°ê³¼

## 기본코드

- CH4 메틴 ppb
- H2S 황화수소 ppm








산업안전보건법의 산업안전보건기준에 관한 규칙을 보면, 맨홀·정화조·우물·터널·암거 등 17개 장소를 ‘밀폐공간’으로 규정하고 있다. 이곳에서 작업하려면 반드시 사전에 주변 공기를 측정해 산소 18% 이상, 메탄가스 10% 이하, 황화수소 10ppm 미만, 일산화탄소 30ppm 미만 등 4가지 수치가 기준치에 부합하는지 확인해야 한다. 어느 하나라도 기준에 맞지 않으면 환기를 하고 기다려야 한다. 작업 전 공기 농도가 정상이라도 작업 도중 언제든지 유독가스가 새어나올 수 있어 계속 환기를 해야 한다.
원문보기:
http://www.hani.co.kr/arti/society/labor/539618.html#csidx89f74948a8f11abba84153c9a5a6638


## 기본코드

3. Work Status
설명 언어코드 WorkStatus_code
- 완료 133 D
- 작업중 145 R
- 계획중 139 W
- 미완료 146 N
4. 센서에 SerialNo 초기화 방법
http://센서 웹주소/SystemConst?snm=시리얼 번호
예시) http://192.168.0.19/SystemConst?snm=wzkkh000000001

5. 센서의 저장 값 보기
http://192.168.0.19/Request?Msg=SavedInfo
(결과 예시)
File Requesting Result
File 1:SystemConst.wzc
size :64
File 2:SystemInfo.wzc
size :208
File 3:APL.wzc
size :2568
File SystemConst.wzc Datas
Str_SN : wzkkh000000002
Str_SysNameInit : wzkk
Str_ComType : wifi
File SystemInfo.wzc Datas
~~Str_Client~~ ~~: AAAAA0~~
Str_cloudAddr : http://192.168.0.9:2020/api/ssd/
Str_sip : 192.168.0.9
~~Str_WkzoneCode~~ ~~:~~ ~~AAA0~~
~~Str_ComType~~ ~~:~~ ~~wifi~~
Int_ComType : 1
Int_SenseTime : 1
Int_ServerPort : 2013
Int_NowAPNum : 0
Int_GiveupCountS : 2
Int_GiveupCountC : 2
Int_RetryCountS : 9
Int_RetryCountC : 1
Int_Revision : 0

<계속>
File APL.wzc Datas
len_APList : 24
len_APListField : 60
AP 0 idxap : 1
AP 0 apssid : junespark-zone
AP 0 appwd : moon6412
AP 1 idxap : 2
AP 1 apssid : junespark-zone-3
AP 1 appwd : wz!QAZ@WSX
File 1:SystemConst.wzc
raw data :
Address : 0x3FFF1A04
0x3FFF1A04: 77 7A 6B 6B 00 00 00 00 00 00 00 00 00 00 00 00 wzkk............
0x3FFF1A14: 00 00 00 00 00 00 00 00 00 00 00 00 00 00 00 00 ................
0x3FFF1A24: 77 7A 6B 6B 68 30 30 30 30 30 30 30 30 32 00 00 wzkkh000000002..
0x3FFF1A34: 00 00 00 00 00 00 00 00 00 00 00 00 00 00 00 00 ................
0x3FFF1A44:
File 2:SystemInfo.wzc
raw data :
Address : 0x3FFF1934
0x3FFF1934: 01 00 00 00 09 00 00 00 02 00 00 00 02 00 00 00 ................
0x3FFF1944: 00 00 00 00 DD 07 00 00 01 00 00 00 01 00 00 00 ................
0x3FFF1954: 77 69 66 69 00 00 00 00 00 00 00 00 00 00 00 00 wifi............
0x3FFF1964: 00 00 00 00 00 00 00 00 00 00 00 00 00 00 00 00 ................
0x3FFF1974: 41 41 5A 31 00 00 00 00 00 00 00 00 00 00 00 00 AAZ1............
0x3FFF1984: 00 00 00 00 00 00 00 00 00 00 00 00 00 00 00 00 ................
0x3FFF1994: 31 39 32 2E 31 36 38 2E 30 2E 39 00 00 00 00 00 192.168.0.9.....
0x3FFF19A4: 00 00 00 00 00 00 00 00 00 00 00 00 00 00 00 00 ................
0x3FFF19B4: 68 74 74 70 3A 2F 2F 31 39 32 2E 31 36 38 2E 30 http://192.168.0
0x3FFF19C4: 2E 39 3A 32 30 32 30 2F 61 70 69 2F 73 73 64 2F .9:2020/api/ssd/
0x3FFF19D4: 00 00 00 00 00 00 00 00 00 00 00 00 00 00 00 00 ................
0x3FFF19E4: 41 41 41 41 41 30 00 00 00 00 00 00 00 00 00 00 AAAAA0..........
0x3FFF19F4: 00 00 00 00 00 00 00 00 00 00 00 00 00 00 00 00 ................
0x3FFF1A04:

6. 센서가 CLOUD서버(localPC는 아님)로 부터 응답 마지막 값
http://192.168.0.19/Request?Msg=lastRequest
(겨리과 예시)
HTTP/1.1 200 OK Cache-Control: no-cache Pragma: no-cache Content-Type: application/json; charset=utf-8 Expires: -1 Server: Microsoft-IIS/10.0 X-AspNet-Version: 4.0.30319 X-Powered-By: ASP.NET Date: Sun, 18 Aug 2019 13:03:56 GMT Content-Length: 23 "[{\"Result\":\"01\"}]"

<계속>
File 3:APL.wzc
raw data :
Address : 0x3FFF1A88
0x3FFF1A88: 41 41 30 00 6A 75 6E 65 73 70 61 72 6B 2D 7A 6F AA0.junespark-zo
0x3FFF1A98: 6E 65 00 6D 6F 6F 6E 36 34 31 32 00 41 41 31 00 ne.moon6412.AA1.
0x3FFF1AA8: 6A 75 6E 65 73 70 61 72 6B 2D 7A 6F 6E 65 2D 33 junespark-zone-3
0x3FFF1AB8: 00 77 7A 21 51 41 5A 40 57 53 58 00 .wz.QAZ@WSX.
Address : 0x3FFF1E88
0x3FFF1E88: 00 00 00 00 04 00 00 00 13 00 00 00 1C 00 00 00 ................
0x3FFF1E98: 20 00 00 00 31 00 00 00 00 00 00 00 00 00 00 00 ...1...........
0x3FFF1EA8: 00 00 00 00 00 00 00 00 00 00 00 00 00 00 00 00 ................
0x3FFF1EB8: 00 00 00 00 00 00 00 00 00 00 00 00 00 00 00 00 ................
0x3FFF1EC8: 00 00 00 00 00 00 00 00 00 00 00 00 00 00 00 00 ................
0x3FFF1ED8: 00 00 00 00 00 00 00 00 00 00 00 00 00 00 00 00 ................
0x3FFF1EE8: 00 00 00 00 00 00 00 00 00 00 00 00 00 00 00 00 ................
0x3FFF1EF8: 00 00 00 00 00 00 00 00 00 00 00 00 00 00 00 00 ................
0x3FFF1F08: 00 00 00 00 00 00 00 00 ........
File log Complpted.

## 모니터링 화면 Layout


작업장 선택


작업장선택


AP 선택

작업장


하수도 막힘공사

로그인

작업장 AP

하수도 막힘공사

AP0001

작업자 선택


작업자 선택


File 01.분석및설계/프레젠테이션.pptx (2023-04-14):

## Smart Box System

20.2.13 박기호 박기용

## 전체 시스템 흐름

시작

장치를 상자에 붙이기

상품등록(장치 설정,셋팅)

RAC 으로
상자 이동

RAC 등록(보관 시작)

출하
장치 초기화

끝

1.시작

이 장치는...
상품이 담겨 보관되는 상자에 장착합니다.
이 장치는 오래 보관되어 있는 상품이 있으면 관리자에게 알려주어 내용물이 출하시기를 놓치지 않도록 관리해주는 역할을 합니다.

그림1.장치의 처음 모습
(상자에 장착하기 전)

## 2.장치를 상자에 붙이기

그림2. 상자에 장착한 모습
(겉에서 보는 시선)
파란색: 장치의 일부

그림3.상자에 장착한 모습
(단면으로 보는 시선)
빨간색 원 : 보관될 상품
빨간색과 파란색 사각형 : 장치의 센서 부분

상자에 장치를 붙일 때는
화면이 붙어있는 부분은 겉에,
센서가 들어있는 부분은 속에 붙입니다.
그 두 부분은 끈으로 서로 연결되어 있습니다.

그림4. 장치를 설정하는 모습
초록색 : Master Key 장치

3.상품등록(장치 설정)

장치를 상자에 붙인 후 보관창고로 이동하기 전에 장치를 설정하는 절차입니다.
새 상품은 센서 고유번호만 저장되어 있는 상태이며 설정을 할 때는 이 장치가 붙여질 상자가 담을 상품에 대한 정보와, 출하시기 위험수준, 센서 설정 값 등을 Master Key 장치를 통해 설정합니다.

## 4.RAC으로 이동

RAC이란?? 보관 창고내에서 일종의 주소,
상품을 보관하는 보관 통입니다.
상품이 담긴 상자를 보관 창고 내로 넣고 나서, 꺼낼 때 상자의 위치를 모르면 찾기에 시간이 걸리고 복잡하므로 RAC 번호를 알면 바로 찾아 출고할 수 있습니다.

5.RAC 등록(보관 시작)

RAC 등록을 하면 관리자에게 출고해야 할 상자들의 위치를 알려주어 신속하게 상자들을 출고할 수 있게 됩니다.
RAC 등록을 하려면 장치의 LCD 화면을 터치해서 RAC 설정 부분으로 들어가 직접 상품이 담긴 상자가 있는 RAC의 번호(예:A-101)를 터치로 입력합니다.
RAC 등록 후에는 출고하기 전까지 보관하며 관리자에게 보관 시간과 위험 여부, 상자 내부 센서 값 등을 일정 기간 간격으로 보냅니다.

^그림5. RAC
왼쪽: RAC을 옆에서 본 입체도
오른쪽:RAC을 위에서 본 평면도

v그림6. RAC 속에 들어간 상자들
박스 정면으로 장치의 화면부분이 보입니다.

## 6. 출하 및 장치 초기화

출하를 할 때면 이 장치의 역할이 다 끝났기 때문에 장치를 상자에서 뗀 후 장치에서 출하처리 과정을 끝낸 뒤에 장치를 초기화하고 무선 충전 패드 위에 올려 놓습니다.

출하처리는
1. 장치의 LCD를 터치
2. 메뉴-출하처리로 가서
3. 출하 버튼을 터치하면 됩니다.

## 전체 시스템 구성요소

중계기

packet

관리자 서버
또는
컴퓨터

MasterKey

packet

초기화 설정 값

장치
(상자)

초기화 설정 값

자체 설정

## Packet 정보 흐름

장치
(상자)

packet

중계기

packet

관리자 서버
또는
컴퓨터

명령어 - 바이트 변환 표
RAC(RAC주소) - 0x01
Data(데이터전달) - 0x02
WAR(경고 상태) - 0x03
DGR(위험 상태) - 0x04
SHP(출고 메시지) - 0x05
RST(초기화 상태) - 0x06
STR(보관 시작) - 0x07

센서 - 바이트 변환 표
bt(베터리잔량) - 0x00
tp(온도) - 0x01
hu(습도) - 0x08
ll(大) - 0xD0
mm(中) - 0xD1
ss(小) - 0xD2

장치 ---> 중계기

중계기 ---> 서버

sbkk b000000001 75/…
1.rac_llAA(^mmV2(^ss0)) 2.dat_tp24.40^hu52.31
3.war_tp24.40^hu52.31
4.dgr_tp24.40^hu52.31
5.shp_tp24.40^hu52.31
6.rst_tp24.40^hu52.31
7.str_dt2020-02-21 19:20:15

ㄱ.RAC 등록 RAC ll “AA” mm ”V2”
ㄴ.데이터전달 DAT bt[75.0f]tp[24.4f]…
ㄷ.경고상태 WAR bt[75.0f]tp[24.4f]…
ㄹ.위험상태 DGR bt[75.0f]tp[24.4f]…
ㅁ.출하처리 SHP bt[75.0f]tp[24.4f]…
ㅂ.장치 재부팅 RST bt[75.0f]tp[24.4f]…
ㅅ.보관시작 STR TimeCode[8바이트]

## 초기화 작업 흐름

관리자 서버
또는
컴퓨터

MasterKey 관리
프로그램

초기화 설정 값

MasterKey

초기화 설정 값

장치
(상자)

순서 | 서버 | <-> | 관리 프로그램 | <-> | MasterKey | <-> | 장치
1 | 기본정보* | -> | 프로그램 내부 저장
2 | | | 번호 저장 | <- | 전달 | <- | 고유번호
3 | | | 고유번호의 기본정보* | -> | 전달 | -> | 초기화(후 연결 끊음)

*기본정보 | 예)
상품명 | 키위
시작시간 | 2020-02-19 10:43:38
경고기간(분) | 5760
위험기간(분) | 7201
보관기간(분) | 10080
전송주기(초) | 43200
보정값 | TP^-5,HU^10
RAC정보 | A(LL) 1(MM) 2(SS)
APPKEY | sbkk00010003

## 마스터키 통신 프로그램

- 마스터키와 통신하여
센서를 초기화해주는 프로그램.

1. 수동 설정 탭
- 센서 기초 정보
- 남은 센서 카운트(들어오는 것 바로 처리)


탭 1. 수동 설정 탭

수동 설정 탭

상품명 | 키위
시작시간 | 2020-02-13
보관기간 | 7
위험기간 | 5

▲

=

수동 설정

데이터 입력

센서 연결이 들어오면

카운터 0이면
작동하지 않는다.

통신 종료

▼

연결 대기

카운터
1 감소,
데이터 송신

23

탭 2. 설정 탭

192.168.0.100:2013/api/

데이터 데이블 열기

개 남음

카운터

연결 상태표시(노:ON)

2. 설정 탭(자동 설정)
- 마스터키 통신(COM포트, 자동검색 기능)
- Api 쿼리, 데이터 관리(데이터 테이블)

상태 표시
로그

마스터키 연결 여부

COM 포트

연결

COM1

자동검색

●

Api 쿼리 주소

자동 설정

Api 쿼리,
저장

가져오기

√

자동으로 가져오기

연결 대기

센서 연결이 들어오면

센서 검색,
데이터 전송(초기화)

통신 종료


등록 : 534개

## 마스터키 – SmartBoxDaemon 통신 규약

1. 작동확인(자동검색 시 사용됨.)
PC -> Masterkey : STX+e+ETX
PC <- Masterkey : STX+ACK(06)+ETX
2. ~~APPKEY~~ ~~입력~~
~~PC ->~~ ~~Masterkey~~ ~~:~~ ~~STX+~~~~AKY~~~~+ENQ+~~~~sbkk00010003~~~~+US(1F~~~~)+~~~~01~~~~+ETX~~
~~PC <-~~ ~~Masterkey~~ ~~:~~ ~~STX+~~~~RTN~~~~+ENQ+~~~~AKY~~~~+US(1F)+~~~~01~~~~+ETX~~
3. ~~이미지~~ ~~입력~~~~(Product Bitmap Pictures)~~
~~PC ->~~ ~~Masterkey~~ ~~:~~ ~~STX+~~~~PBP~~~~+ENQ+~~ ~~(968 Byte bitmap~~ ~~Data)~~ ~~+US(1F~~~~)+~~~~01~~~~+ETX~~
~~PC <-~~ ~~Masterkey~~ ~~:~~ ~~STX+~~~~RTN~~~~+ENQ+~~~~PBP~~~~+US(1F~~~~)+~~~~01~~~~+ETX~~
4. 센서 접근 (컴퓨터 <- 마스터키)
PC <- Masterkey : STX+NDT+ENQ+sbkkb000000001+US(1F)+01+ETX
5. 데이터 전송 (컴퓨터 -> 마스터키)
PC -> Masterkey : STX+NDT+ENQ+(Hex)LENGTH(4Byte)+hexCode(LEN*2 Byte)+US(1F)+01+ETX
PC <- Masterkey : STX+RTN+ENQ+NDT+US(1F)+01(00)+ETX


## 장치를 대체해야 할 때 (2020/02/18)

장치 A를 교환해야 하는 상황이다.
교환 후에도 원래대로(설계대로 이어서) 진행돼야 한다.
ㄱ. 장치 A자리에 B를 대체한다.
1 . 장치 B를 A의 데이터로 초기화한다.
2 . 서버의 A의 SN으로 저장된 항목을 B의 것으로 바꾼다.
(서버가 B의 데이터도 인식할 수 있도록 해야 한다.)
과제1 . RAC번호 저장 문제
RAC에 저장하면 RAC메세지를 서버에 주게 되는데 그러면 데이터 ’시작시간’ 이 바뀌어
출하시간, 위험기간까지 모두 그만큼 밀리게 된다.
-> 재배치한다면 STA 신호를 보내지 않음. API 통해서 재배치 관련 작업 수행.

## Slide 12


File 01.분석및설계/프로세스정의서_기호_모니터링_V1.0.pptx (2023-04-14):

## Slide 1

1. 사용자 정책

사용자 구분 | 사용자 분류 | 사용자 분류별 권한 | 예외사항 및 참고사항
관리자 | (일반)관리자 | *모든 기능 센서 조회 기능 | 아이디/비밀번호 로그인 후 접근 가능

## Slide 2

관리자 전체 흐름도

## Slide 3

업무 처리 흐름도
단 계 | 설계 | 프로세스 ID | 없음 | 프로세스 명 | 관리자 전체 흐름도 | 작 성 자 | 박기호 | 승 인 자
설 명 | 공연예술통합관리시스템의 관리자 전체 업무 처리 흐름도

사용자구분 | 사용자분류 | 업무 절차
관리자 | 관리자

시작

로그인

메인

다른 탭 클릭

종료버튼 클릭

clip_image001

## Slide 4

I. 로그인

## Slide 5

3. 업무처리 흐름도

PC-M-01

로그인

로그인

사용자구분 | 사용자분류 | 업무 절차
사용자 | 관리자

N

시작

PC-M-01-01

로그인

PC-M-01-02

정보 일치 여부 확인

Y

인증 성공 여부

종료

N

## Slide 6

PC-M-01

로그인

로그인

엑티비티 | | | 수행자 | 산출물 | | 비고
ID | 명 | 설명 | | 입력 | 출력
PC-M-01-01 | 로그인 | 아이디/비밀번호를 통한 로그인 | 관리자 | 아이디/비밀번호
PC-M-01-02 | 정보 일치 여부 확인 | 아이디/비밀번호를 설정파일에 설정된 서버로 전송 | 관리자 | 서버주소, 아이디/비밀번호 | 인증여부 | API(http)를 통해 송수신한다.

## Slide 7

II. 메인

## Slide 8

PC-M-02

메인

메인

사용자구분 | 사용자분류 | 업무 절차
관리자 | 관리자

PC-M-02-01

RAC 탐색기

시작

PC-M-02

메인 화면

PC-M-02-02

데이터 불러오기

PC-M-02-03

전송주기

PC-M-02-04

센서 화면

종료

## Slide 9

3. 업무처리 흐름도

PC-M-02

메인

메인

엑티비티 | | | 수행자 | 산출물 | | 비고
ID | 명 | 설명 | | 입력 | 출력
PC-M-02-01 | RAC 탐색기 | RAC 탐색
PC-M-02-02 | 데이터 불러오기 | 센서의 데이터를 불러옴. 센서 화면 내용 갱신
PC-M-02-03 | 전송주기 | 전송주기에 따라 센서 화면의 내용이 갱신됨.
PC-M-02-04 | 센서 화면 | 선택한 RAC 또는 센서의 내용을 출력함.

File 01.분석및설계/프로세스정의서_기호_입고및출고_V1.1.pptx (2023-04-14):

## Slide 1

1. 사용자 정책

사용자 구분 | 사용자 분류 | 사용자 분류별 권한 | 예외사항 및 참고사항
관리자 | (일반)관리자 | *모든 기능 박스 등록 기능 센서 교체 기능 마스터키 포트 설정 기능 언어 설정 기능 선세 리스트 불러오기 기능 센서 출고 기능 | 아이디/비밀번호 로그인 후 접근 가능

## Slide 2

관리자 전체 흐름도

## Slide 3

업무 처리 흐름도
단 계 | 설계 | 프로세스 ID | 없음 | 프로세스 명 | 관리자 전체 흐름도 | 작 성 자 | 박기호 | 승 인 자
설 명 | 공연예술통합관리시스템의 관리자 전체 업무 처리 흐름도

사용자구분 | 사용자분류 | 업무 절차
관리자 | 관리자

시작

로그인

센서 리스트

입고/박스등록

센서교체

설정

출고

종료

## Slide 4

I. 로그인

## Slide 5

3. 업무처리 흐름도

PC-M-01

로그인

로그인

사용자구분 | 사용자분류 | 업무 절차
사용자 | 관리자

N

시작

PC-M-01-01

로그인

PC-M-01-02

정보 일치 여부 확인

clip_image001

Y

인증 성공 여부

종료

N

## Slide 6

PC-M-01

로그인

로그인

엑티비티 | | | 수행자 | 산출물 | | 비고
ID | 명 | 설명 | | 입력 | 출력
PC-M-01-01 | 로그인 | 아이디/비밀번호를 통한 로그인 | 관리자 | 아이디/비밀번호
PC-M-01-02 | 정보 일치 여부 확인 | 아이디/비밀번호를 설정파일 속에 설정된 서버로 전송 | 관리자 | | 인증여부 | API(http)를 통해 송수신한다.

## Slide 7

II. 센서 리스트

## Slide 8

PC-M-02

센서 리스트

센서 리스트

사용자구분 | 사용자분류 | 업무 절차
관리자 | 관리자

PC-M-02-01

센서 리스트

시작

PC-M-02

센서 리스트

PC-M-02-02

검색

PC-M-02-03

창 숨기기(트레이)

PC-M-02-04

교체 센서 더블클릭

PC-M-04

교체 탭으로 이동

종료

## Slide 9

3. 업무처리 흐름도

PC-M-02

센서 리스트

센서 리스트

엑티비티 | | | 수행자 | 산출물 | | 비고
ID | 명 | 설명 | | 입력 | 출력
PC-M-02-01 | 센서 리스트 | 현재 작동 중인 센서들의 정보를 리스트로 표시 제일 윗부분을 클릭해 정렬을 할 수도 있음
PC-M-02-02 | 검색 | 텍스트박스에 있는 키워드를 리스트에 보이는 모든 내용에 검색하여 일치하는 행만 출력하도록 검색함
PC-M-02-03 | 창 숨기기(트레이) | 트레이 아이콘으로 창을 숨김
PC-M-02-04 | 교체 센서 더블클릭 | 더블클릭한 센서의 정보를 교체 탭으로 넘김. | | 더블클릭한 센서의 정보

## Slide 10

III. 입고/박스 등록

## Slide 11

PC-M-03

입고/박스등록

입고/박스등록

사용자구분 | 사용자분류 | 업무 절차
관리자 | 관리자

시작

PC-M-03

입고/박스등록

PC-M-03-01

센서 인식 대기

PC-M-03-02

관리자 입력

센서 초기화 및
박스 등록

PC-M-03-03

종료

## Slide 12

3. 업무처리 흐름도

PC-M-03

입고/박스등록

입고/박스등록

엑티비티 | | | 수행자 | 산출물 | | 비고
ID | 명 | 설명 | | 입력 | 출력
PC-M-03-01 | 센서 인식 대기 | 센서/박스 등록을 위한 준비 센서의 전원을 켜 컴퓨터에 인식시킴. | 관리자
PC-M-03-02 | 관리자 입력 | 박스 코드, 보관시간 등을 입력한다. | 관리자 | 보관시간 등 센서정보, 박스 번호, RAC 번호
PC-M-03-03 | 센서/박스 등록 | API를 통해서 서버에 박스/센서 정보 전송, 정상등록여부 확인 | | | 성공여부

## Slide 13

IV. 센서 교체

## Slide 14

PC-M-04

센서 교체

센서 교체

사용자구분 | 사용자분류 | 업무 절차
관리자 | 관리자

시작

PC-M-04

센서 교체

PC-M-04-01

센서 준비

PC-M-04-02

센서 교체

종료

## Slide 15

3. 업무처리 흐름도

PC-M-04

센서 교체

센서 교체

엑티비티 | | | 수행자 | 산출물 | | 비고
ID | 명 | 설명 | | 입력 | 출력
PC-M-04-01 | 센서 준비 | 교체될 센서와 새로운 센서를 지정한다. 교체될 센서 : “PC-M-02”로 가서 교체될 센서를 더블클릭한다. 새로운 센서 : “PC-M-04 화면에서” 새로운 센서의 전원을 켜서 인식시킨다. | 관리자 | 교체될 센서와 새로운 센서의 번호
PC-M-04-02 | 센서 교체 | API를 통해 서버에서 교체 처리함. | | | 성공여부

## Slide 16

V. 설정

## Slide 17

PC-M-05

설정

설정

사용자구분 | 사용자분류 | 업무 절차
관리자 | 관리자

PC-M-05-01

마스터키 통신포트 설정

시작

PC-M-05

메인

PC-M-05-02

언어 설정

PC-M-05-03

센서 정보 불러오기

종료

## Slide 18

3. 업무처리 흐름도

PC-M-05

설정

설정

엑티비티 | | | 수행자 | 산출물 | | 비고
ID | 명 | 설명 | | 입력 | 출력
PC-M-05-01 | 마스터키 통신포트 설정 | 마스터키 연결 에 필요한 COM포트 설정 자동검색 기능 이용
PC-M-05-02 | 언어 설정 | 언어 설정
PC-M-05-03 | 센서 정보 불러오기 | 센서 리스트 다시 불러오기

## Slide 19

VI. 출고

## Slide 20

PC-M-06

출고

출고

사용자구분 | 사용자분류 | 업무 절차
관리자 | 관리자

시작

PC-M-06

출고

PC-M-06-01

출고

종료

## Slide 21

3. 업무처리 흐름도

PC-M-06

출고

출고

엑티비티 | | | 수행자 | 산출물 | | 비고
ID | 명 | 설명 | | 입력 | 출력
PC-M-06-01 | 출고 | 센서에서의 출고 작업 Out 버튼을 누른다. | 관리자

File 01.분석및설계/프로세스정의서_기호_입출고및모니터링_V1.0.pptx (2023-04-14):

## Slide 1

목차
1. 사용자 정책 ............................................................................................................. 2
2. 업무처리 흐름도 ....................................................................................................... 6
(관리자 전체 흐름도)............................................................................................. 3
PC-M-01 (로그인)............................................................................................... 5
PC-M-02 (센서 리스트)........................................................................................ 8
PC-M-03 (입고/박스등록)..................................................................................... 11
PC-M-04 (센서 교체)........................................................................................... 14
PC-M-05 (설정).................................................................................................. 17
PC-M-06 (모니터링)............................................................................................ 20
PC-M-07 (출고).................................................................................................. 23

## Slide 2

0. 표기법

이벤트 시작/종료

데이터베이스

PC-01-01

프로세스

PC-01-01

수작업 프로세스

PC-01-06

문서

PC-01-06

수작업 문서

clip_image001

분기

데이터 흐름
(주요 엔터티 수준을 화살표 위에 표시)

※ 위 기호 외에 필요한 내용은 프로젝트 자체적으로 추가하여 사용할 수 있다.

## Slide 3

1. 사용자 정책

사용자 구분 | 사용자 분류 | 사용자 분류별 권한 | 예외사항 및 참고사항
관리자 | (일반)관리자 | *모든 기능 박스 등록 기능 센서 교체 기능 마스터키 포트 설정 기능 언어 설정 기능 선세 리스트 불러오기 기능 센서 출고 기능 | 아이디/비밀번호 로그인 후 접근 가능 창고에서의 기반으로 한다.

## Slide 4

관리자 전체 흐름도

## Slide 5

업무 처리 흐름도
단 계 | 설계 | 프로세스 ID | 없음 | 프로세스 명 | 관리자 전체 흐름도 | 작 성 자 | 박기호 | 승 인 자
설 명

사용자구분 | 사용자분류 | 업무 절차
관리자 | 관리자

시작

로그인

센서 리스트

입고/박스등록

센서교체

설정

모니터링

출고

종료

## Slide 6

I. 로그인

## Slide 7

3. 업무처리 흐름도

PC-M-01

로그인

로그인

사용자구분 | 사용자분류 | 업무 절차
사용자 | 관리자

N

시작

PC-M-01-01

로그인

PC-M-01-02

정보 일치 여부 확인

Y

인증 성공 여부

종료

N

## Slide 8

PC-M-01

로그인

로그인

엑티비티 | | | 수행자 | 산출물 | | 비고
ID | 명 | 설명 | | 입력 | 출력
PC-M-01-01 | 로그인 | 아이디/비밀번호를 통한 로그인 | 관리자 | 아이디/비밀번호
PC-M-01-02 | 정보 일치 여부 확인 | 아이디/비밀번호를 설정파일 속에 설정된 서버로 전송 | 관리자 | | 인증여부 | API(http)를 통해 송수신한다.

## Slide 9

II. 센서 리스트

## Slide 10

PC-M-02

센서 리스트

센서 리스트 (탭 “리스트“)

사용자구분 | 사용자분류 | 업무 절차
관리자 | 관리자

PC-M-02-01

센서 리스트

시작

PC-M-02

센서 리스트

PC-M-02-02

검색

종료

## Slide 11

3. 업무처리 흐름도

PC-M-02

센서 리스트

센서 리스트 (탭 “리스트“)

엑티비티 | | | 수행자 | 산출물 | | 비고
ID | 명 | 설명 | | 입력 | 출력
PC-M-02-01 | 센서 리스트 | 현재 작동 중인 센서들의 정보를 리스트로 표시 -제일 윗부분을 클릭해 정렬할 수 있음
PC-M-02-02 | 검색 | 텍스트박스에 있는 키워드를 검색하여 검색한 행을 리스트로 출력

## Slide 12

III. 입고/박스 등록

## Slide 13

PC-M-03

입고/박스등록

입고/박스등록 (탭 “박스등록”)

사용자구분 | 사용자분류 | 업무 절차
관리자 | 관리자

시작

PC-M-03

입고/박스등록

PC-M-03-01

센서 인식 대기

PC-M-03-02

관리자 입력

센서 초기화 및
박스 등록

PC-M-03-03

종료

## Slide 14

3. 업무처리 흐름도

PC-M-03

입고/박스등록

입고/박스등록 (탭 “박스등록”)

엑티비티 | | | 수행자 | 산출물 | | 비고
ID | 명 | 설명 | | 입력 | 출력
PC-M-03-01 | 센서 인식 대기 | 센서/박스 등록을 위한 준비 센서의 전원을 켜 컴퓨터에 인식시킴. | 관리자
PC-M-03-02 | 관리자 입력 | 박스 코드, 보관시간 등을 입력한다. | 관리자 | 보관시간 등 센서정보, 박스 번호, RAC 번호
PC-M-03-03 | 센서/박스 등록 | 서버로 박스/센서 정보 전송 | | | | API(HTTP)통신을 이용한다.

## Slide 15

IV. 센서 교체

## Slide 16

PC-M-04

센서 교체

센서 교체 (탭 “교체”)

사용자구분 | 사용자분류 | 업무 절차
관리자 | 관리자

시작

PC-M-04

센서 교체

PC-M-04-01

센서 준비

PC-M-04-02

센서 교체

종료

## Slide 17

3. 업무처리 흐름도

PC-M-04

센서 교체

센서 교체 (탭 “교체”)

엑티비티 | | | 수행자 | 산출물 | | 비고
ID | 명 | 설명 | | 입력 | 출력
PC-M-04-01 | 센서 준비 | 교체될 센서와 새로운 센서를 지정한다. 교체될 센서 지정 : 탭“리스트”로 이동하여 교체될 센서를 더블클릭한다. 새로운 센서 지정 : 탭“교체” 화면에서 새로운 센서의 전원을 켜서 인식시킨다. | 관리자 | 교체될 센서와 새로운 센서의 번호
PC-M-04-02 | 센서 교체 | API를 통해 서버에서 교체 처리함. | | | 성공여부 | API(HTTP)통신을 이용한다

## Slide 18

V. 설정

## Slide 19

PC-M-05

설정

설정 (탭 “설정“)

사용자구분 | 사용자분류 | 업무 절차
관리자 | 관리자

PC-M-05-01

마스터키 통신포트 설정

시작

PC-M-05

설정

PC-M-05-02

언어 설정

종료

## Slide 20

3. 업무처리 흐름도

PC-M-05

설정

설정 (탭 “설정“)

엑티비티 | | | 수행자 | 산출물 | | 비고
ID | 명 | 설명 | | 입력 | 출력
PC-M-05-01 | 마스터키 통신포트 설정 | 마스터키 연결 에 필요한 COM포트 설정 포트 자동검색 기능 | | | | 드라이버 설치 필요
PC-M-05-02 | 언어 설정 | 언어 설정 | | | | 언어 DB파일

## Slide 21

VI. 모니터링

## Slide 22

PC-M-06

모니터링

모니터링

사용자구분 | 사용자분류 | 업무 절차
관리자 | 관리자

시작

PC-M-06

모니터링

PC-M-06-01

창고선택

PC-M-06-02

RAC선택

모니터링

PC-M-06-03

주기 선택

PC-M-06-04

Chart Form 선택

PC-M-06-05

종료

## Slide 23

3. 업무처리 흐름도

PC-M-06

모니터링

모니터링

엑티비티 | | | 수행자 | 산출물 | | 비고
ID | 명 | 설명 | | 입력 | 출력
PC-M-06-01 | 창고선택 | 창고 선택 | 관리자
PC-M-06-02 | RAC선택 | RAC 선택 | 관리자
PC-M-06-03 | 주기 선택 | 주기 선택 | 관리자
PC-M-06-04 | Chart Form 선택 | Chart형 다이어그램 | 관리자
PC-M-06-05 | 모니터링 | 1000개 이상 : 간략 다이어그램 1000개 이하 : 상세 다이어그램

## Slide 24

VII. 출고

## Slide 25

PC-M-07

출고

출고

사용자구분 | 사용자분류 | 업무 절차
관리자 | 관리자

시작

PC-M-07

출고

PC-M-07-01

출고

종료

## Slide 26

3. 업무처리 흐름도

PC-M-07

출고

출고

엑티비티 | | | 수행자 | 산출물 | | 비고
ID | 명 | 설명 | | 입력 | 출력
PC-M-07-01 | 출고 | 센서에서의 출고 작업 Out 버튼을 누른다. | 관리자

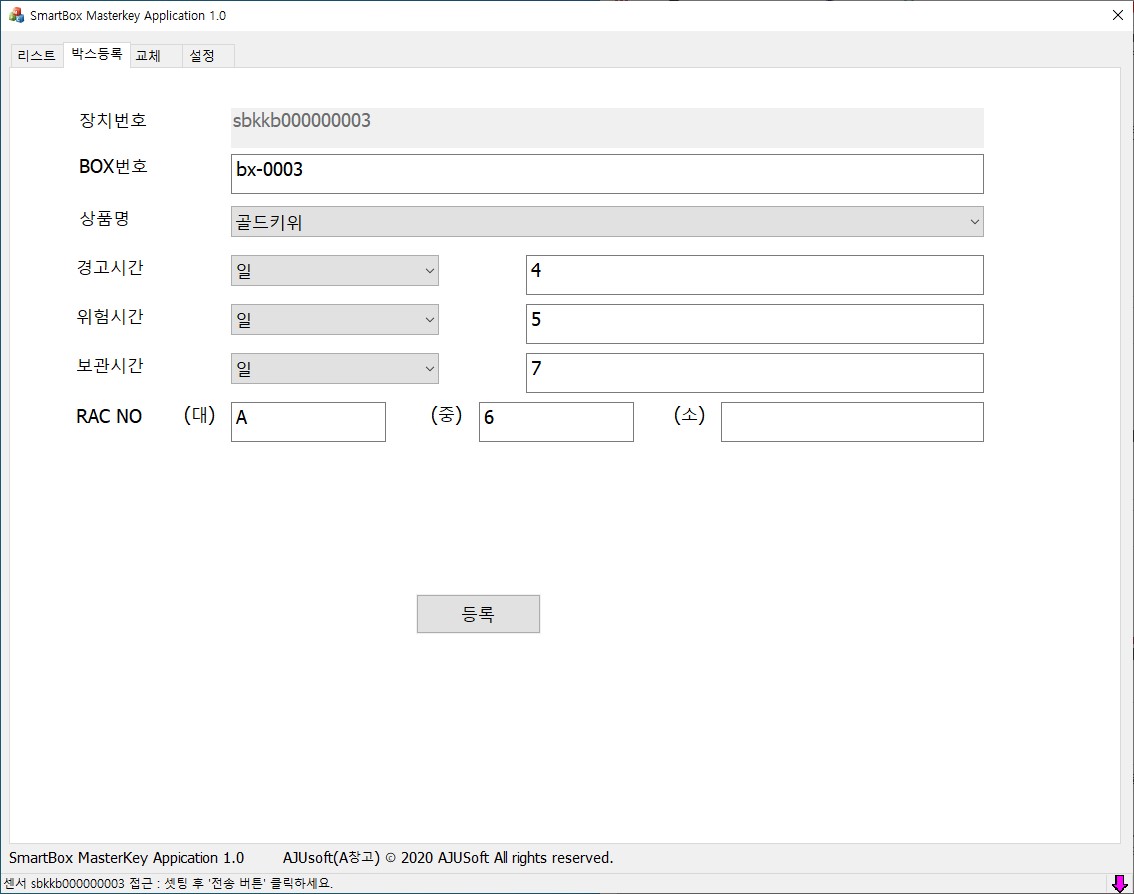
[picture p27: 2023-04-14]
MasterKey Application 센서등록.jpg

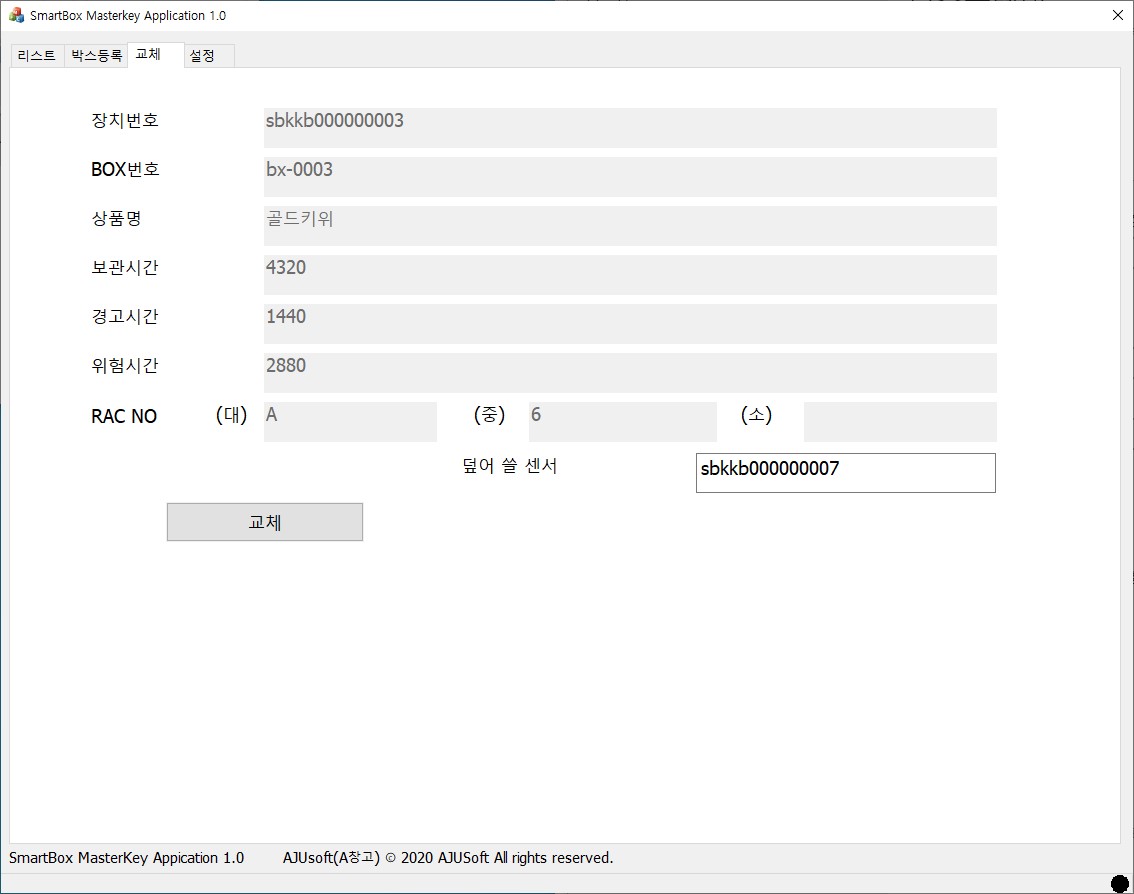
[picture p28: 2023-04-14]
MasterKey Application 센서교체(더블클릭).jpg

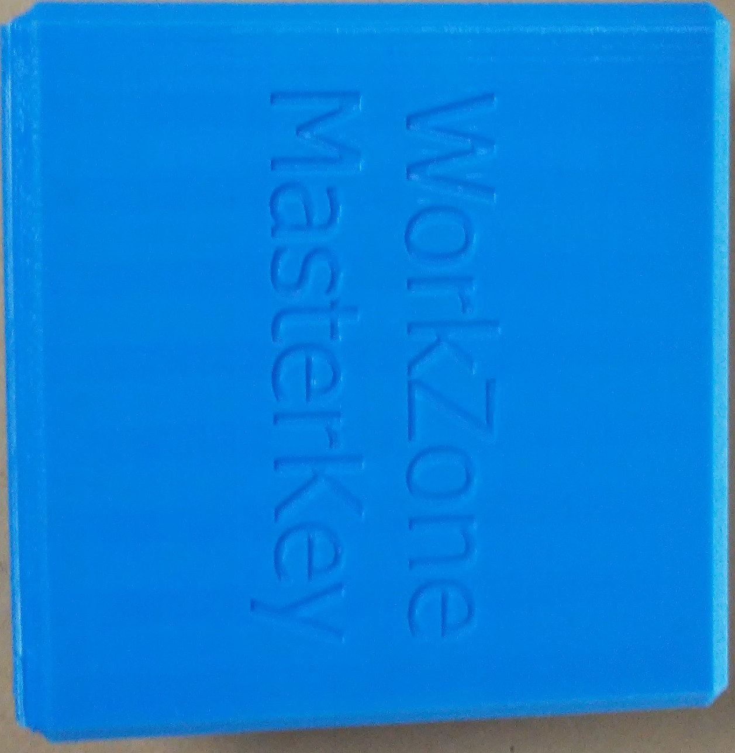
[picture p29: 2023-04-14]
01.분석및설계/Image/마스터키.jpg

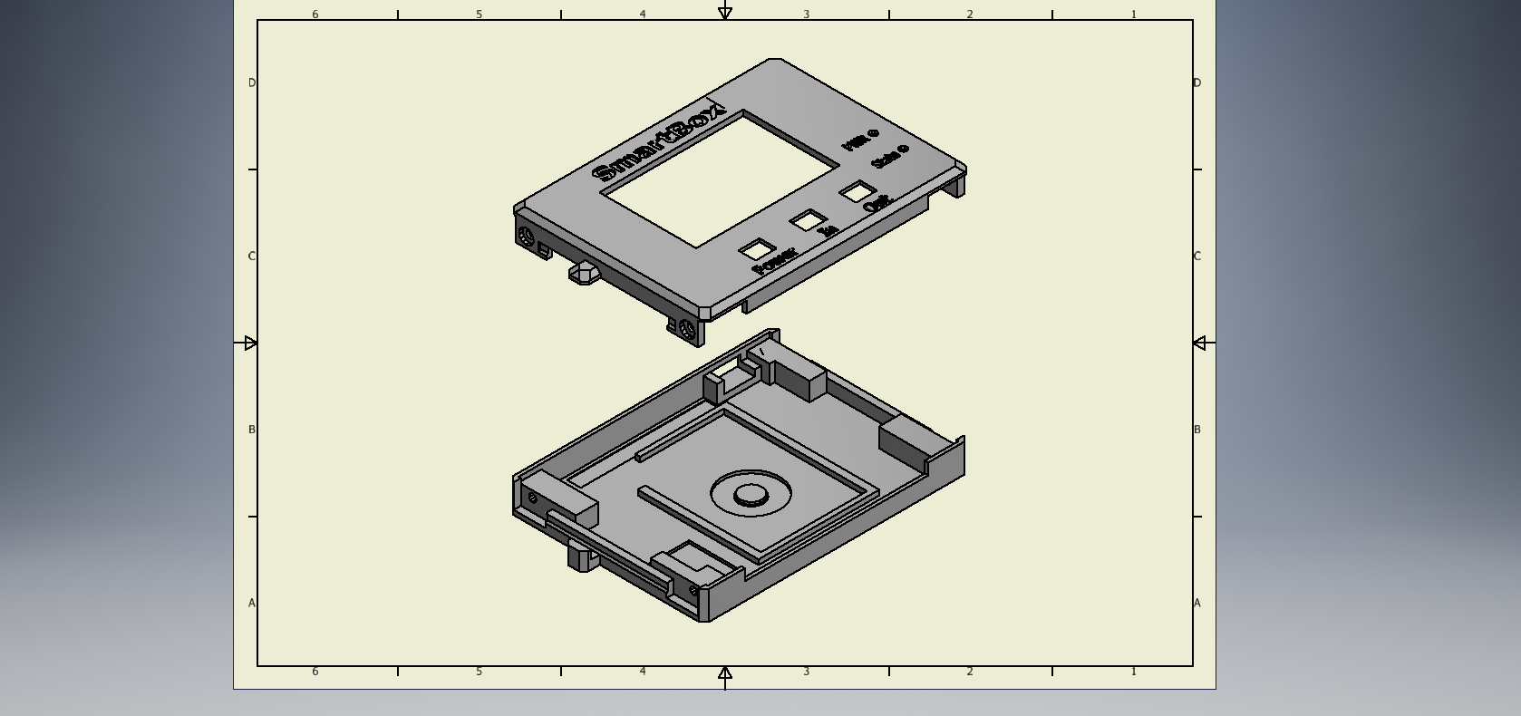
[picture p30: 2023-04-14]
3D Model/SmartBox.bmp

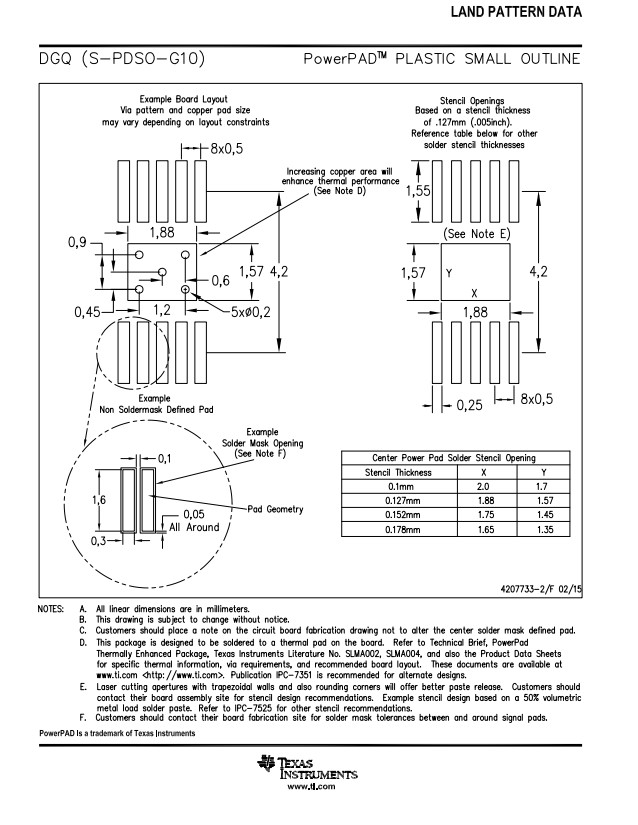
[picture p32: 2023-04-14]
회로/ORCAD/DFN10.jpg

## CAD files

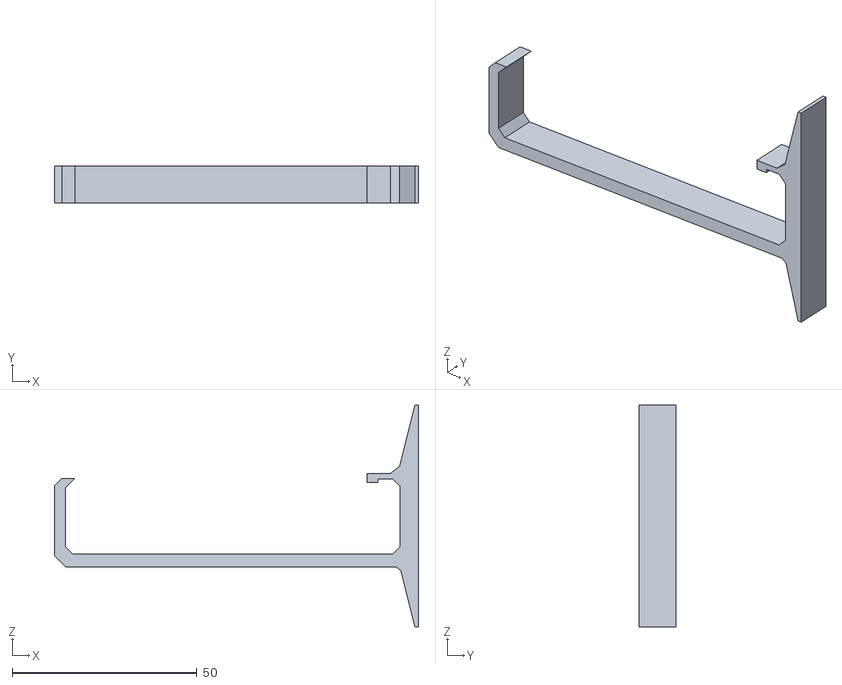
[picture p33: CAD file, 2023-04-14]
3D Model/Charger/Leg3.stl
98.5 x 10.0 x 60.0

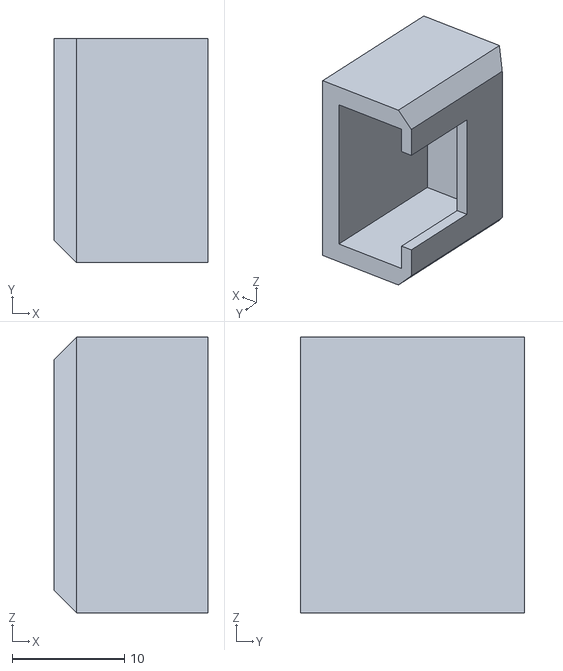
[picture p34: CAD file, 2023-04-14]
3D Model/Connector/Connect_Female.stl
13.7 x 20.0 x 24.6

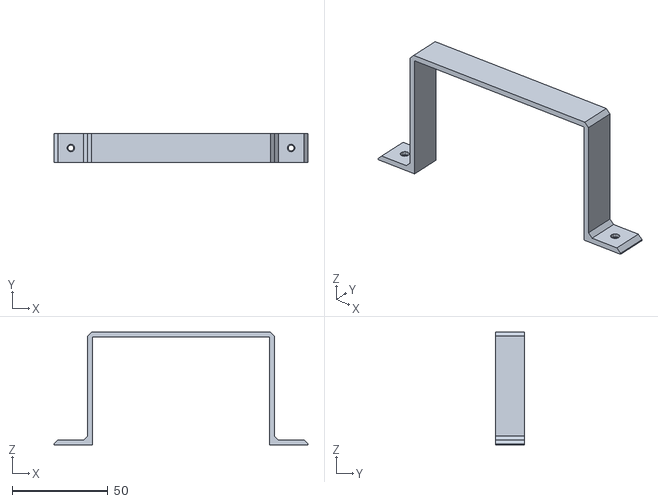
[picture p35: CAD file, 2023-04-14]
3D Model/Gateway/Gateway Support_Beauty.stl
132.4 x 15.0 x 58.7

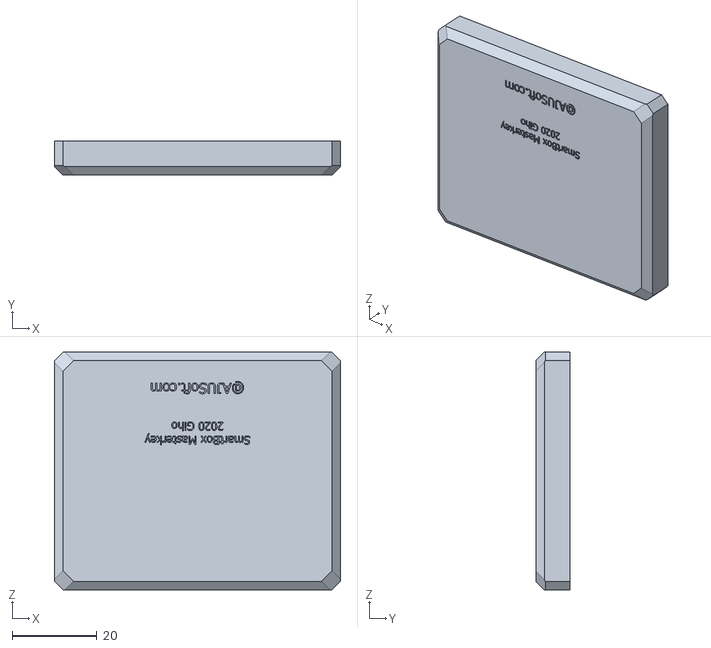
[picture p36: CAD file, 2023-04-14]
3D Model/MasterKey/MasterKey2_Bottom.stl
67.4 x 8.10 x 56.0

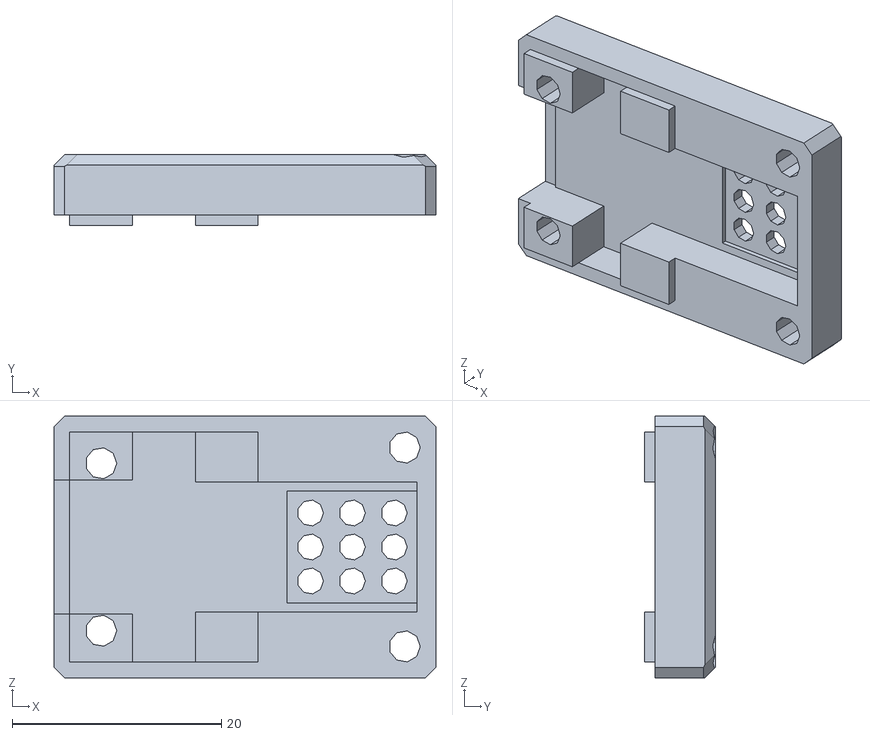
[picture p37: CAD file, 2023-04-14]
3D Model/SensorCase/SensorCase_Top.stl
36.5 x 6.75 x 25.0

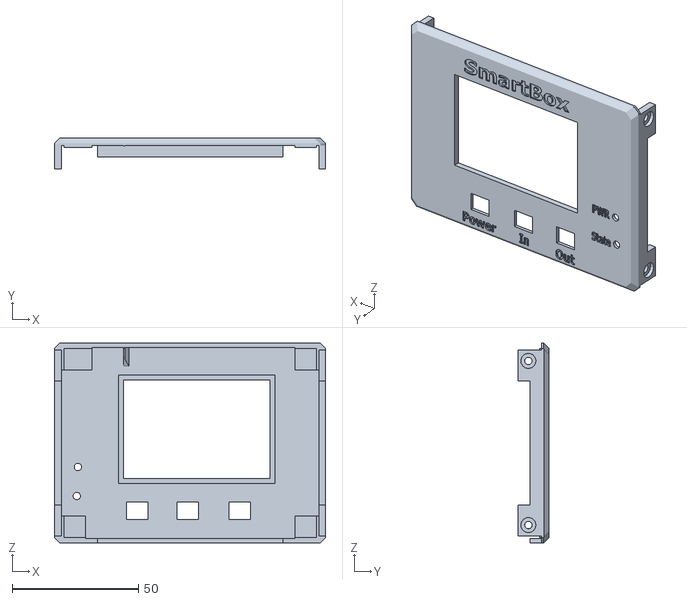
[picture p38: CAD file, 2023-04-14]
3D Model/SmartBox/SmartBox2_Top.stl
107.3 x 12.3 x 79.0

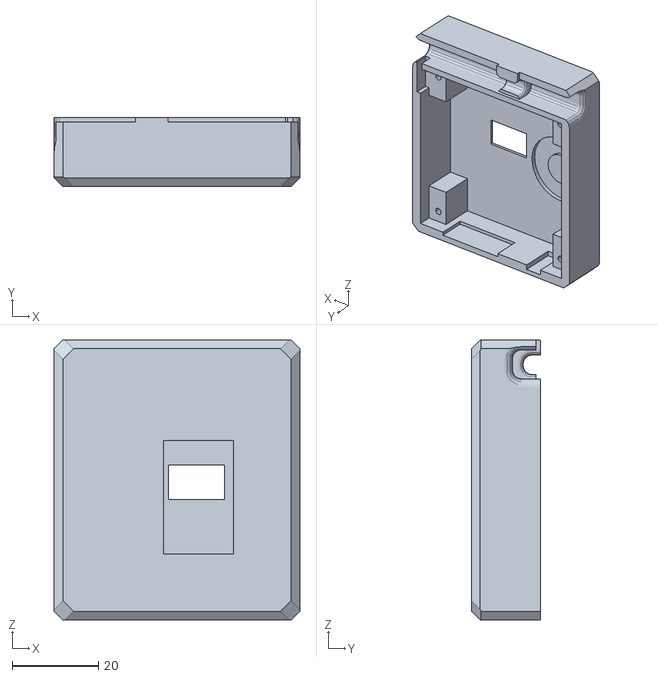
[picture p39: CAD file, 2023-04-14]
3D Model/Workzone/Body/Body_Bottom.stl
57.0 x 16.0 x 65.0

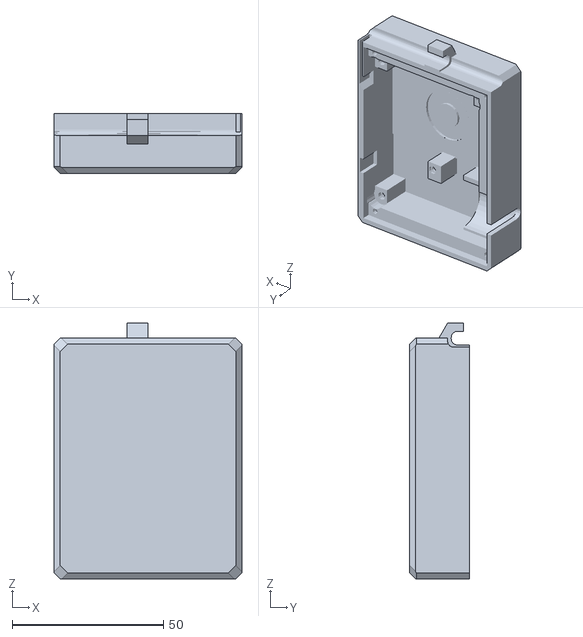
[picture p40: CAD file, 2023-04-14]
3D Model/Workzone/HelmetOxy/HelmetOxyBottom.stl
62.0 x 19.8 x 84.5

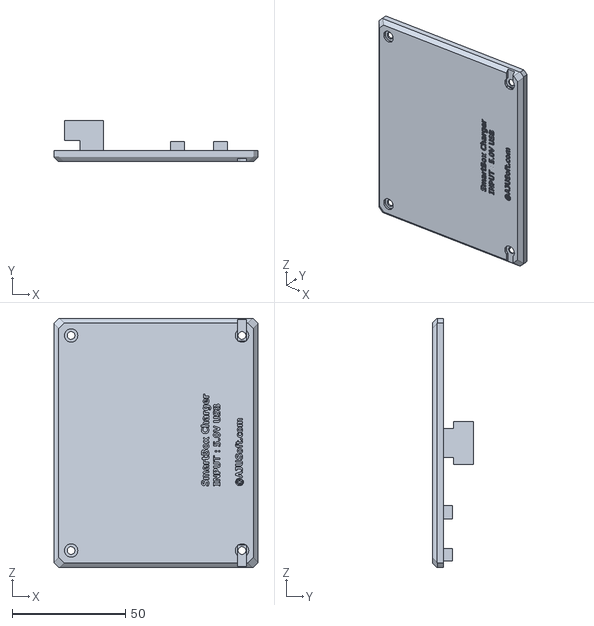
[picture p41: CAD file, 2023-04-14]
3D Model/Charger/Charger_Bottom.stl
90.0 x 18.3 x 110.0

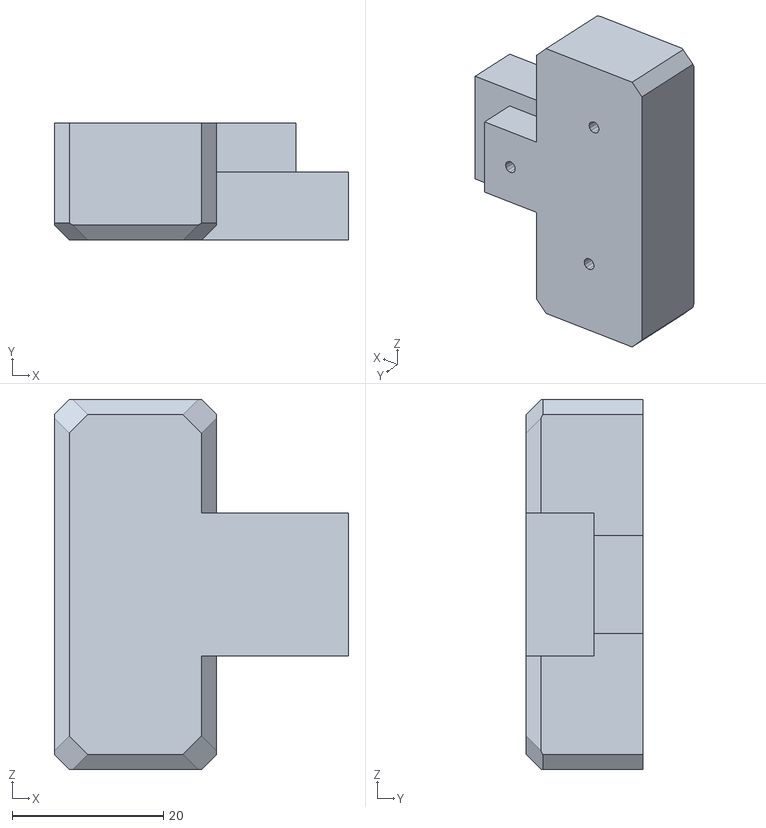
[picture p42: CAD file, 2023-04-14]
3D Model/Connector/Connect_Male.stl
39.0 x 15.5 x 49.0

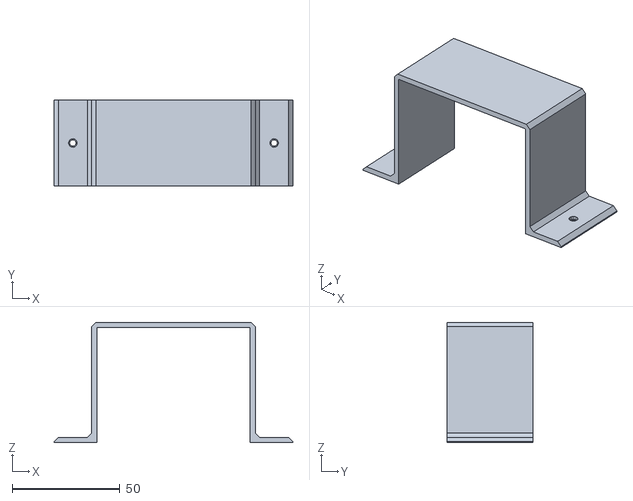
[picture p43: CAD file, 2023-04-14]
3D Model/Gateway/Gateway Support-top_Beauty.stl
110.9 x 40.0 x 55.9

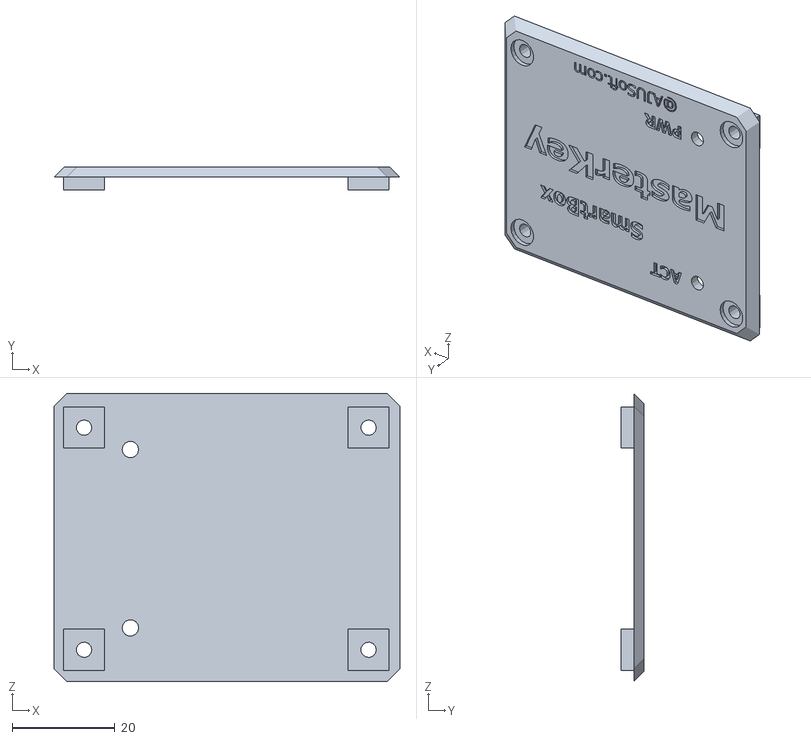
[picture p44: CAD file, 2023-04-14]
3D Model/MasterKey/MasterKey2_Top.stl
67.2 x 4.50 x 56.0

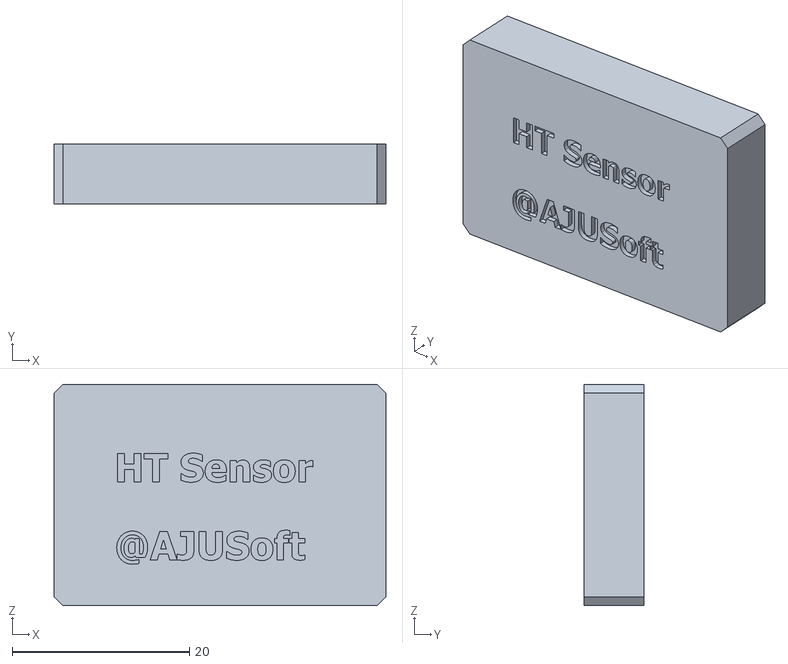
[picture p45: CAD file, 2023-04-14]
3D Model/SensorCase/SensorCase_Bottom.stl
37.5 x 6.80 x 25.0

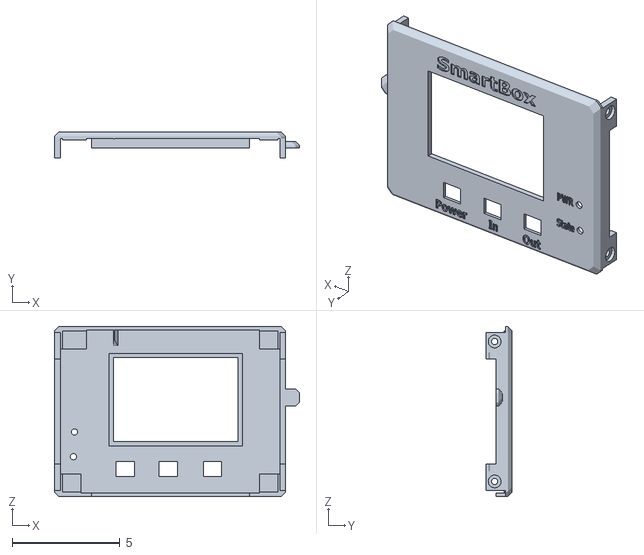
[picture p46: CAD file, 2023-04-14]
3D Model/SmartBox/SmartBox3_Top.stl
11.4 x 1.23 x 7.90

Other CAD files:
3D Model/Workzone/Body/Body_Top.stl
3D Model/Charger/Charger_Top.stl
3D Model/SmartBox/Button.stl
3D Model/SmartBox/SmartBox3_Bottom.stl
3D Model/Charger/ChargerBottom_Beauty.ipt
3D Model/Charger/ChargerTop_Beauty.ipt
3D Model/Charger/Leg3.ipt
3D Model/Connector/Connect_Female_Beauty.ipt
3D Model/Connector/Connect_Male_Beauty.ipt
3D Model/Gateway/Gateway Support_Beauty.ipt
3D Model/MasterKey/MasterKey_Beauty.ipt
3D Model/SensorCase/SensorCase.ipt
3D Model/SensorCase/SensorCase_Beauty.ipt
3D Model/SmartBox/Button.ipt
3D Model/SmartBox/SmartBox_Beauty.ipt
3D Model/Workzone/Body/Body_Bottom_Beauty.ipt
3D Model/Workzone/Body/Body_Top_Beauty.ipt

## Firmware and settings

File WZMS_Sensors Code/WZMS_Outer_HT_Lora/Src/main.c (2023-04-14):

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

/* Includes ------------------------------------------------------------------*/
#include "main.h"

/* USER CODE BEGIN Includes */
#include "userardu.h"
#include "lmic.h"
#include "userardu.h"
#include "RFInterface.h"
#include "giuart.h"
#include "NRF/nrf24.h"
#include "WZMSCore.h"
/* USER CODE END Includes */

/* USER CODE BEGIN PD */
extern GPIO_Pin Unused_Pin;
#define SW_SERIAL_UNUSED_PIN Unused_Pin
/* USER CODE END PD */

I2C_HandleTypeDef hi2c1;

UART_HandleTypeDef hlpuart1;

SPI_HandleTypeDef hspi1;

TIM_HandleTypeDef htim16;

void SystemClock_Config(void);
static void MX_GPIO_Init(void);
static void MX_SPI1_Init(void);
static void MX_I2C1_Init(void);
static void MX_LPUART1_UART_Init(void);
static void MX_TIM16_Init(void);
/* USER CODE BEGIN PFP */
extern volatile void BtnINT();
extern char uart_getTM(uint32_t timeout);
extern char uart_get(void);
extern void uart_set(char ch);
void snm2DevEUI(char* snm);
/* USER CODE END PFP */

/* USER CODE BEGIN 0 */

extern u1_t APPEUI[8];
void __attribute__((const)) error_Handler(const char* const file, const uint16_t line){
	xprintf("Assertion detected!!\r\nlocale : %s:%d\r\n",file,line);
  digitalWrite(byte2GPIO_Pin(0xB4),1);
  digitalWrite(byte2GPIO_Pin(0xB5),0);
}
void HAL_TIM_PeriodElapsedCallback(TIM_HandleTypeDef *htim)
{
  if(htim->Instance == TIM16)WZMS_LEDLoop();
}
/* USER CODE END 0 */

/**
  * @brief  The application entry point.
  * @retval int
  */
int main(void)
{
  

  /* MCU Configuration--------------------------------------------------------*/

  /* Reset of all peripherals, Initializes the Flash interface and the Systick. */
  HAL_Init();

  /* Configure the system clock */
  SystemClock_Config();

  /* Initialize all configured peripherals */
  MX_GPIO_Init();
  MX_SPI1_Init();
  MX_I2C1_Init();
  MX_LPUART1_UART_Init();
  MX_TIM16_Init();
  /* USER CODE BEGIN 2 */
//HAL_TIM_Base_Start_IT(&htim15);    // <-----------  change to your setup
  HAL_TIM_Base_Start_IT(&htim16);    // <-----------  change to your setup
  __HAL_SPI_ENABLE(&hspi1);            // <-----------  change to your setup
  
  //UART_init(uart_get,uart_set,uart_getTM);
  
  Serial = &hlpuart1;
  debug_init();

  hal_set_failure_handler(error_Handler);
  
  println("Init End.!!");
  //println("nrf24_init!!");


  extern GPIO_Pin debugled;//PB7
  //led = byte2GPIO_Pin(0xB7);
  debugled = byte2GPIO_Pin(0xA8);

  //Start = 1;
  //blink = WZMS_millis();
  
	//ResetCutline = 10;
	

	//CType = "lora";

  println("RFInit!!");
  println("APPKEY = %s",printBin(NwkCode,16));
  
  //RFsend();
  
	WZMS_Init();//WZMS Initialize

  //GPIO_Pin dio = byte2GPIO_Pin(0xA0);
  //attachInterrupt(digitalPinToInterrupt(dio),BtnINT,FALLING);
  //Pinpullstate(GPIOA,GPIO_PIN_0,GPIO_PULLUP);
  /* USER CODE END 2 */

  /* Infinite loop */
  /* USER CODE BEGIN WHILE */
  while (1)
  {
    /* USER CODE END WHILE */

    /* USER CODE BEGIN 3 */
    //println("RFloop");
    WZMSLoop();//WZMS Loop
	  os_runloop_once();
  }
  /* USER CODE END 3 */
}

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


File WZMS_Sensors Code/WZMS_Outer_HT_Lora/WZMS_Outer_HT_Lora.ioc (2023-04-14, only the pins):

Mcu.UserName=STM32L412K8Tx
PA0-CK_IN.GPIO_Label=LORA_DIO1
PA0-CK_IN.Signal=GPXTI0
PA1.Signal=GPIO_Output
PA10.Signal=I2C1_SDA
PA11.GPIO_Label=SW_Reset
PA11.Signal=GPXTI11
PA2.Signal=LPUART1_TX
PA3.GPIO_Label=NRF_CE
PA3.Signal=GPIO_Output
PA4.GPIO_Label=NRF_CSN
PA4.Signal=GPIO_Output
PA5.Signal=SPI1_SCK
PA6.Signal=SPI1_MISO
PA7.Signal=SPI1_MOSI
PA8.GPIO_Label=DebugLED
PA8.Signal=GPIO_Output
PA9.Signal=I2C1_SCL
PB0.GPIO_Label=LORA_NSS
PB0.Signal=GPIO_Output
PB1.GPIO_Label=LORA_DIO0
PB1.Signal=GPXTI1
PB5.GPIO_Label=LED_GREEN
PB5.Signal=GPIO_Output
PB6.Signal=USART1_TX
PB7.Signal=USART1_RX

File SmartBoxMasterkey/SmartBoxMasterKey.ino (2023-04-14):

#include <SPI.h>
#include "Addstr.h"
#include "SBMasterKey.h"
#include "RFInterface.h"
#include "nrf24.h"
#include "print.h"

void ReceivingData();
void delay_ms(int delay);
void ICACHE_RAM_ATTR RF_INTERRUPT();
void ICACHE_RAM_ATTR Sensor_Interrupt();
extern volatile int RecvINT;
volatile int TransmitINT = 0;

extern void RtnToSerial(String format,String rtnnum);
extern int Infobuflen;

extern "C" void RFInit();
extern "C" void RFLoop();

void setup() {
  // put your setup code here, to run once:
  ESP.wdtDisable();
  // put your setup code here, to run once:
  Serial.begin(2000000);
  Serial.println("\nStart!!\n");
  //xfunc_out = senduart;

  //     PINMAP
  //GPIO0  : CE
  //GPIO4  : CSN
  //GPIO5  : IRQ
  //GPIO12 : MISO
  //GPIO13 : MOSI
  //GPIO14 : SCK
  //..
  println("0");
  pinMode(0, OUTPUT);
  pinMode(4, OUTPUT);
  pinMode(5, INPUT);
  pinMode(12, INPUT);
  pinMode(13, OUTPUT);
  pinMode(14, OUTPUT);
  println("1");
  SPI.begin();
  SPI.pins(14, 12, 13, 4);
  SPI.setDataMode(0);
  println("2");
  SPI.setFrequency(8000000);//8MHz

  pinMode(15, INPUT);
  attachInterrupt(15, Sensor_Interrupt, RISING);
  /* simple greeting message */

  RFInit();

  attachInterrupt( 5, RF_INTERRUPT, FALLING);

  Process_getkey_preset();
  //nrf24_ce_digitalWrite(0);
}

void senduart(uint8_t ch)
{
  Serial.print(ch);
}
void sendstr(char *str)
{
  Serial.print(str);
}
void sendstrln(char *str)
{
  Serial.println(str);
}
//int count;
void loop() {
  //println("loop() start");
  ESP.wdtDisable();
  yield();
  Port_uartprocessing();
  //FFSWebloop();
  //println("Port_uartprocessing() end");
  MSKeyloop();
  
  RFLoop();

  if(TransmitINT)
  {
    Process_Access("sbkkb000000009");
    Process_getkey();
    if(Infobuflen>1)
      RtnToSerial("NDT","01");
    else//1 byte : Cancel    0 byte : Fail
      RtnToSerial("NDT","00");
    delay(100);
    TransmitINT = 0;
  }
  /*
    nrf24_csn_digitalWrite(0);
    PORTC = (PORTC&(~0x01))|!(PORTC&0x01);
    uint8_t data = spi_transfer(0x11);
    nrf24_csn_digitalWrite(1);
    print("0x11->0x%02x\n",data);
    delay_ms(100);
  */
  //printDetails();

  // nrf24_powerDown();

  //_delay_ms(10);
}
//NRF Protocol (Standard Mode : 4Byte)

// 0x02) Requesting BINARY file
//Inital        : Header 3Byte   + ComingAddr 5Byte      + SerialNum 14Byte + Extra dummy's  (Total 0xLL Byte)
//1-1. Receive  : 0xAA 0x55 0x02 | 0xCD 0xCD 0xCD 0xCD 0xCD | "wzkkh000000001" | 0x00... 0x00
//1-2A.TxIF     : 0xAA 0x55 0xNN      0xFF(Firm Version. It's no use Downloading the file. Its binary is new.)->END.
//1-2. Transmit Data  Sending binary file...
//Every 10 Transmission, it must return ACK. or error block to retry or break.
//N-1. Transmit :  -> 32Byte Transmision
//10N-1.Transmit: 0xAB 0xBA 0xAB 0xBA 0x01 0xNN.... 0x00 (is ACK?) (NN : he number of Packets in Next Sector)
//10N-1A.Receive: 0xAC(ACK) 0x00 0x00 0x00 0x00.... 0x00 (It's ACK.)------>Repeat N-1.
//10N-1B.Receive: 0xA0(NAK) 0xNN(Request count for present Transmission)
//10N-2.Transmit:  -> 32Byte reTransmision
//10N-3A.Receive: 0xA0(NAK) 0xNN(Request count for present Transmission)-->Repeat 10N-3.
//10N-3B.Receive  0xAC(ACK) 0x00 0x00 0x00 0x00.... 0x00 (It's ACK.)------>Repeat N-1.

//10N-B.Transmit: 0xAB 0xBA 0xAB 0xBA 0x04 0x00.... 0x00 (TheTransmission is over.)

//Receive 1-1
// 0x01) Requesting ResetBtn Interface
//Inital        : Header 3Byte    + ComingAddr 5Byte        + SerialNum 14Byte + Extra dummy's  (Total 0xLL Byte)
//1-1. Receive  : 0xAA 0x55 0x01  |  0xCD 0xCD 0xCD 0xCD 0xCD | "wzkkh000000001"   0x00 ... 0x00

//1-2. Transmit : 0xB0 0xLN 0xef   (LN : Sending count , ef : eof line bytes(len = LN*32 + ef))
//N-1. Transmit : Data~
//LN-1A.Receive : 0xAC(ACK) 0x00 0x00 0x00 0x00.... 0x00 (It's ACK.)-------------------->End.
//LN-1B.Receive : 0xA0(NAK) 0xNN(Request count for present Transmission) 0x00.... 0x00-->Repeat N-1.

void ICACHE_RAM_ATTR RF_INTERRUPT()
{
  RecvINT = 1;
}
void ICACHE_RAM_ATTR Sensor_Interrupt()
{
  TransmitINT = 1;
}


extern "C" void delay_us(uint64_t us) {
  uint64_t start = micros64();
  while (micros64() - start <= us)
  {
    yield();
  }
}

uint8_t spi_transfer(uint8_t tx)
{
  return SPI.transfer(tx);
}
void spi_transfers(uint8_t *tx, uint8_t *rx, int len)
{
  SPI.transferBytes(rx, tx, len);
}
void nrf24_ce_digitalWrite(int pin)
{
  digitalWrite(0, pin);
}
void nrf24_csn_digitalWrite(int pin)
{
  digitalWrite(4, pin);
}

void delay_ms(int delays)
{
  delay(delays);
}

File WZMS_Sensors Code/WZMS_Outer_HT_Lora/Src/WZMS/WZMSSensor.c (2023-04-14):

#include "WZMSSensor.h"
#include "WZMSCore.h"


#ifdef __cplusplus
extern "C"
{
#endif

#define Debug println


void I2C_BusCheck();
void ina219begin();
void MAX30205begin(void);
float getBusVoltage_V();
void UserInitalize();

//void UART_INIT();
#define UART_INIT() 

int UART_Baud;

extern DATA_SystemConst data_SystemConst;
extern DATA_SystemInfo data_SystemInfo;

// Setup for the WZMS Sensor Processing Unit
int  WZMSSensor_init()
{
  UART_INIT();
	Sense_Info = data_SystemConst.senseinfo;//"_0tp_1ox_2ps_3bt_4tp";  //System constant(Sensor Value)
  UART_Baud = 0;//9600;


  Battery_Full = data_SystemConst.bt_high, Battery_Low = data_SystemConst.bt_low;

  UserInitalize();
  return 0;
}

extern char *format_What[13];
int format_a(char* str)
{
	char buf[3];
	memcpy(buf,str,2);
	buf[2] = 0;

	for(int i=0;i<sizeof(format_What)/sizeof(char*);i++)
		if(isEqualText(format_What[i],buf))return i;

	return 0xFF;
}
// it's Equalvalent of Sensordata[i][63] to Port_SType_Table[i]
//uint8_t Port_SType_Table[5]
void PrintPortInit(char* point) {
	int a = 0; char* Format = (char*)point;//_0tp_1ox_2ps_3bt_4tp
	for(int i=0;i<5;i++)SensorData[i][63] = 0xFF;
	while (1) {
		if (*Format == 0)break;
		else if (*Format == '_')
		{
			Format++;
			a = *Format - '0';//the number of the PrintPort
			int port = a;
			a = 0; while (1)if ('0' <= Format[a] && Format[a++] <= '9')break;// the 'a' is the length of the 'tp','ox',etc.
			a++;
			
      SensorData[port][63] = format_a(Format+1);
			Debug("Format+1 = %s",Format+1);
			Debug("SensorData[%d][63] = %d",port,SensorData[port][63]);
			
			Format += a;
		}
		Format++;
	}

}

void DHT12processing();

char* resstr[5]={"HAL_OK","HAL_ERROR","HAL_BUSY","HAL_TIMEOUT","OTHER"};
void UserInitalize(){
  //WriteMemory();
  if(UART_Baud)
  {
    SensorUart->Init.BaudRate = UART_Baud;
    if (HAL_HalfDuplex_Init(SensorUart) != HAL_OK)
    {
      Error_Handler();
    }
  }

  println("APPKEY = %s",printBin(NwkCode,16));

  UART_INIT();
  //if(Port_Usage[3])Port_UART->begin(38400);
  //Port_I2C->begin();
  println("I2C_BusCheck()");
 
  I2C_BusCheck();

	println("AT24C16 Test");

	/*
  //AT24C16 Testing Code 
	uint8_t i[256] = {0x00,0x01,0x02,0x03,0x04,0x05,0x06,0x07,0x08,0x09,0x0A,0x0B,0x0C,0x0D,0x0E,0x0F},a[3] = {0x04,0x05,0x06},addr;
	
	uint8_t res;

  for(int d=0;d<16;d++)
  {
    for(int j=0;j<16;j++)i[j]=(d<<4) | j;
    WriteEEPROM(d<<4,i,16);
  }

	memset(i,0xFE,0x20);

	ReadEEPROM(0x00,i,256);
	println(PrintMemoryMap(0x00,i, 256, 16));


  for(int d=0;d<8;d++)
  {
    for(int j=0;j<32;j++)i[j]=(d<<5) | j;
    WriteEEPROM(d<<5,i,32);
  }

	memset(i,0xFE,0x20);

	ReadEEPROM(0x00,i,256);
	println(PrintMemoryMap(0x00,i, 256, 16));


  for(int d=0;d<4;d++)
  {
    for(int j=0;j<64;j++)i[j]=(d<<6) | j;
    WriteEEPROM(d<<6,i,64);
  }

	memset(i,0xFE,0x20);

	ReadEEPROM(0x00,i,256);
	println(PrintMemoryMap(0x00,i, 256, 16));
  */

  
  // Initialize the INA219.
  // By default the initialization will use the largest range (32V, 2A).  However
  // you can call a setCalibration function to change this range (see comments).
  //ina219.begin();
  // Or to use a lower 16V, 400mA range (higher precision on volts and amps):
  //ina219.setCalibration_16V_400mA();
  //double Resistance = 1;
  //ina219.ina219_currentDivider_mA=200 * Resistance;
  //ina219.ina219_powerMultiplier_mW=0.1f / Resistance;
  ina219begin();
  //getBusVoltage_V();
  WZMSSensor_processing(-1);
}

//float readTemperature();
//float read_Vcc();

/*
void oxyprocessing(char* dat);
void co2processing(char* dat);
void cmprocessing(char* dat,int len);

uint16_t UART_avail = 0;
uint16_t UART_focus = 0;
char UARTRcvBuf[128];
void UART_INIT()
{
    HAL_UART_Receive_IT(SensorUart,UARTRcvBuf,1);
}
uint8_t uart_available()
{
  return UART_avail>=UART_focus ? UART_avail-UART_focus : UART_avail-UART_focus+128;
}
uint8_t UART_readBuf()
{
  if(UART_focus==127)
  {
    UART_focus=0;
    return UARTRcvBuf[127];
  }
  else if(UART_focus != UART_avail)
  {
    return UARTRcvBuf[UART_focus++ + (UART_focus!=0?-1:+127)];
  }
  else return 0;
}
void HAL_UART_RxCpltCallback(UART_HandleTypeDef *huart)
{
  if(huart->Instance == SensorUart->Instance)
  {
    HAL_UART_Receive_IT(SensorUart,UARTRcvBuf+UART_avail,1);
    if(UART_avail<127)
    {
      UART_avail++;
    }
    else UART_avail=0;
  }
}

int cnt = 0, no = 0;
int Received=1;
uint32_t start;
char SeBuf[65];
int Recording;
int focus;

#define CHSTART(x,l)   (' '<x && x <= 127)//(x == 0xFF) //
#define CHEND(x,l)     (x == '\n')//(l>=8) //

void Port_uartprocessing() {
  while(uart_available()){
		uint8_t ch = UART_readBuf();
		//println("avail : %d 0x%02X",uart_available(),ch);
		//Serial.println((String)"avail : " + Port_UART->available());
		if(Recording){
			if(CHEND(ch,focus)){
				Recording=0;
				SeBuf[focus]=0;
				println("Buf : %s", SeBuf);
				//println("Buf : %s", printBin(SeBuf,focus));
				oxyprocessing(SeBuf);
				//co2processing(SeBuf);
				//cmprocessing(SeBuf,focus);
			}
			else SeBuf[focus++]=ch;
		}else if(CHSTART(ch,focus)){
			SeBuf[0]=ch;
      Recording=1;
			focus=1;
		}
	}
}
;
uint8_t codata[16];
void cmprocessing(char* dat, int len)
{
	float *cm_Data = (float*)&(codata[0]);
	float *cm_pre = (float*)&(codata[4]);
	float *cm_no = (float*)&(codata[8]);
	float *count = (float*)&(codata[12]);
	if(*count >= 10)*count = 0;
  (*count)++;

  char* point = memchr(dat,0x04,len);
  if(!point) (*cm_no)++;
  else
  {
    //println("Data : %s", printBin(point,8));
    //println("len  : %d", len);

    //println("Gas Type : 0x%02X", point[0]);
    //println("Unit     : 0x%02X", point[1]);
    //println("No.dec   : 0x%02X", point[2]);
    //println("Concent  : %d", point[3]<<8 | point[4]);
    //println("Max      : %d", point[5]<<8 | point[6]);
    //println("Checksum : 0x%02X", point[7]);
    
    *cm_Data = (point[3]<<8 | point[4])*0.1;
    //println("Concent  : %s", float_print(*cm_Data));
    //println("Concent  : %s", float_print((point[3]<<8 | point[4])*0.1));
  }

  if(*count == 10 && *cm_no > 8)//기준이 잘못됨.
  {
    *cm_pre = *cm_Data;
    *cm_no = 0;
  }

  if(abs(*cm_Data - *cm_pre) < 10)// 기준 갱신 (변화량이 10 이상이면)
  {
    *cm_pre = *cm_Data;
  }
  else // 실패라면
  {
    (*cm_no)++;
    *cm_Data = *cm_pre;
  }

}
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

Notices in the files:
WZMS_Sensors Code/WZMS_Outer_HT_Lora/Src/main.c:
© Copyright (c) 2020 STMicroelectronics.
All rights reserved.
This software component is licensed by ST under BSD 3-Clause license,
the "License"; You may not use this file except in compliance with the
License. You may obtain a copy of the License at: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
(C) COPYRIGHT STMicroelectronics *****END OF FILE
